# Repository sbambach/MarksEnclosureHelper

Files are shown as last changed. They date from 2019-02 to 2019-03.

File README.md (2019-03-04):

# Mark's Enclosure Helper 

This is an OpenSCAD script for generating a two peice hinged box, with
rounded corners, lid, interlocking rims, snap fit, magnet, or screw
closures, and easy places for adding cutouts or additions to any
face. All features are optional and specified by defining a few simple
variables. Included utility functions make perforations, text and
image decorations possible in a single line of code.

Additional parts inculding dovetails and belt clips are also included.

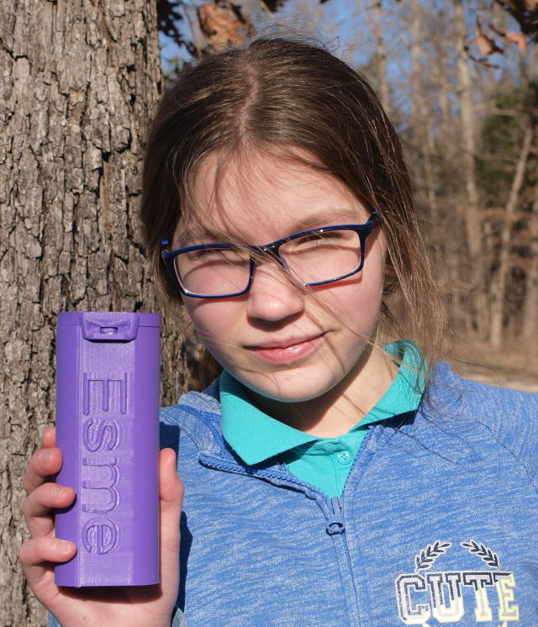
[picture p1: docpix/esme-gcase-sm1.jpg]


-----------------

We've tried to make this useable for those less comfortable with or even
new to OpenSCAD. See the "Let's Build a Bee Box" tutorial: 

[LETSBUILD-beebox.md](LETSBUILD-beebox.md).

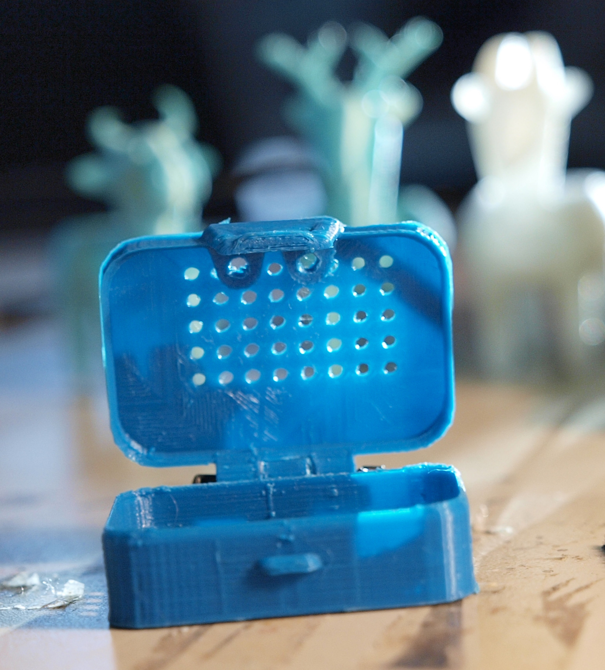
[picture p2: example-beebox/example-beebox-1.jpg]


-----------------

Experienced OpenSCAD users may wish to skip straight to the docs:

[REFERENCE.md](REFERENCE.md) 

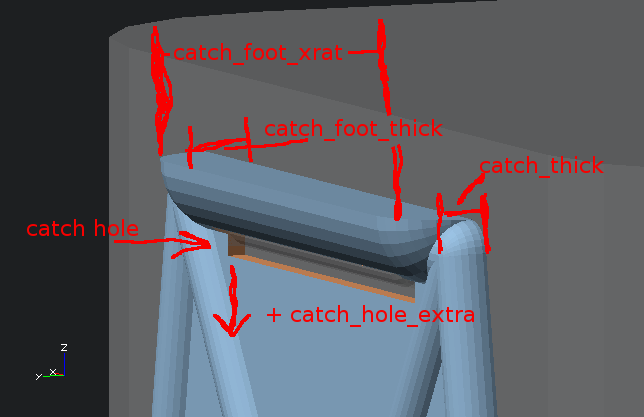
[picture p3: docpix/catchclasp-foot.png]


or to hacking at the included examples:

-----------------

[Eyeglass Belt Case](example-eyeglass-beltcase/)

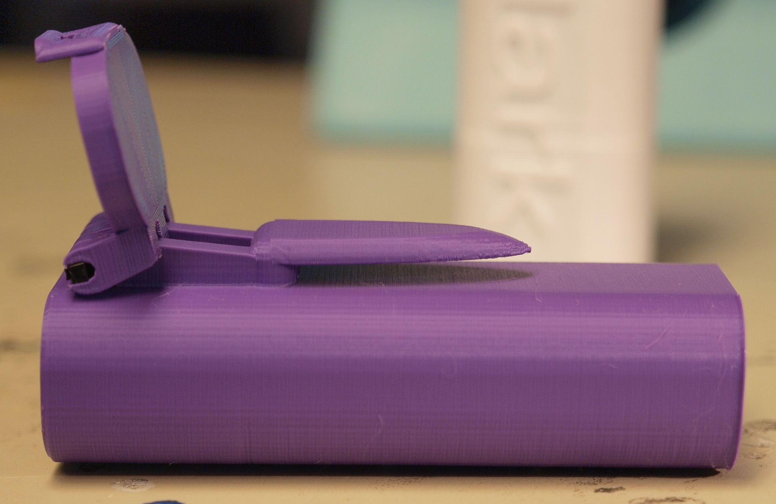
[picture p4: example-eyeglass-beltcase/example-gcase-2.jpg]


-----------------

[Interlocking Parts Boxes](example-partbox/)

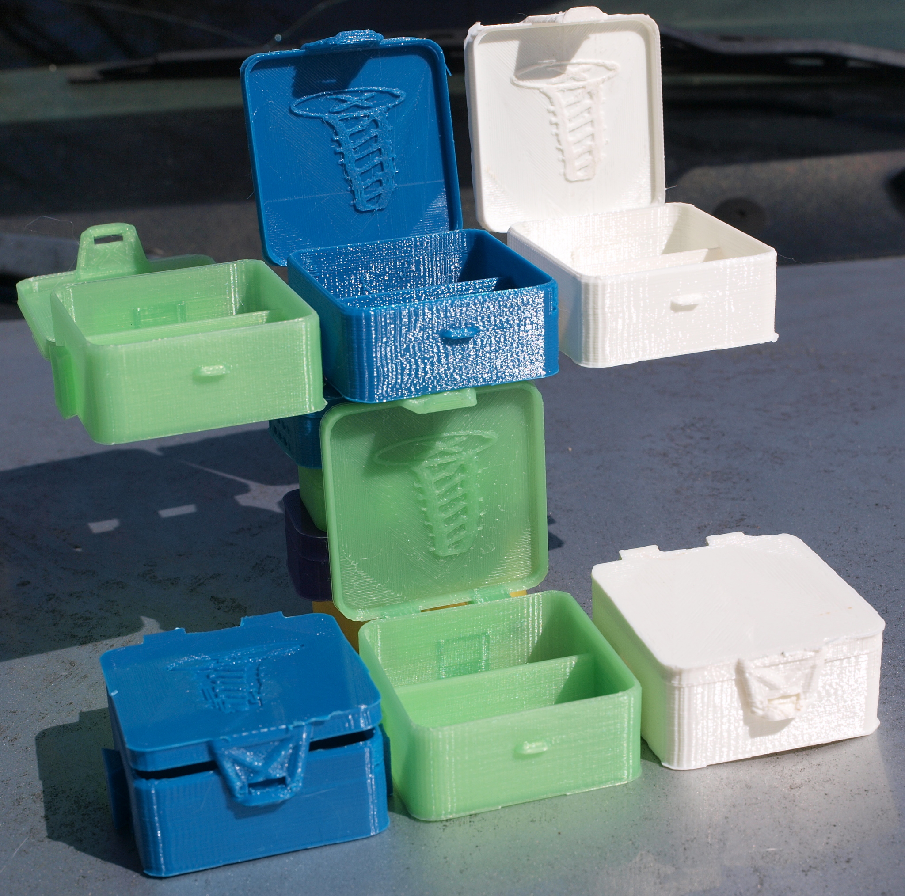
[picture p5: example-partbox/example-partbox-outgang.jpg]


-----------------

[Mini Mint Tin with Magnet or Catch Clasp](example-minitin/)

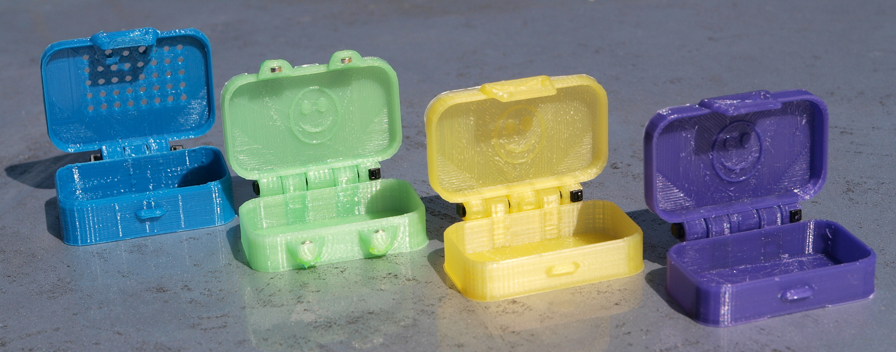
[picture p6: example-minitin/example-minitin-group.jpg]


-----------------

[Neddle Keeper with Sizing Guage](example-needlekeeper/)

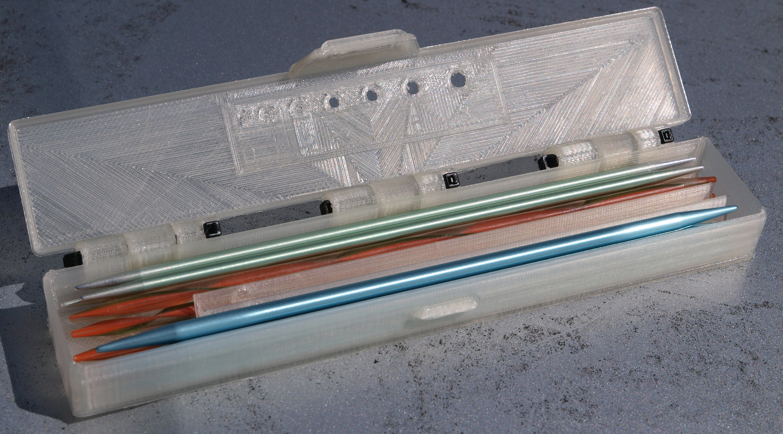
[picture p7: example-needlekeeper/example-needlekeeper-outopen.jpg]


-----------------

[4 Spool Thread Keeper](example-threadkeeper/)

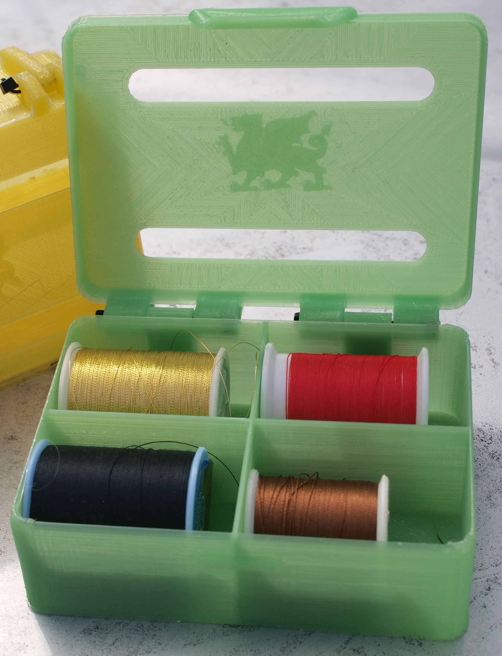
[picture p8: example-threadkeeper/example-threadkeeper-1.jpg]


-----------------

[Card Deck Case](example-cardcase/)

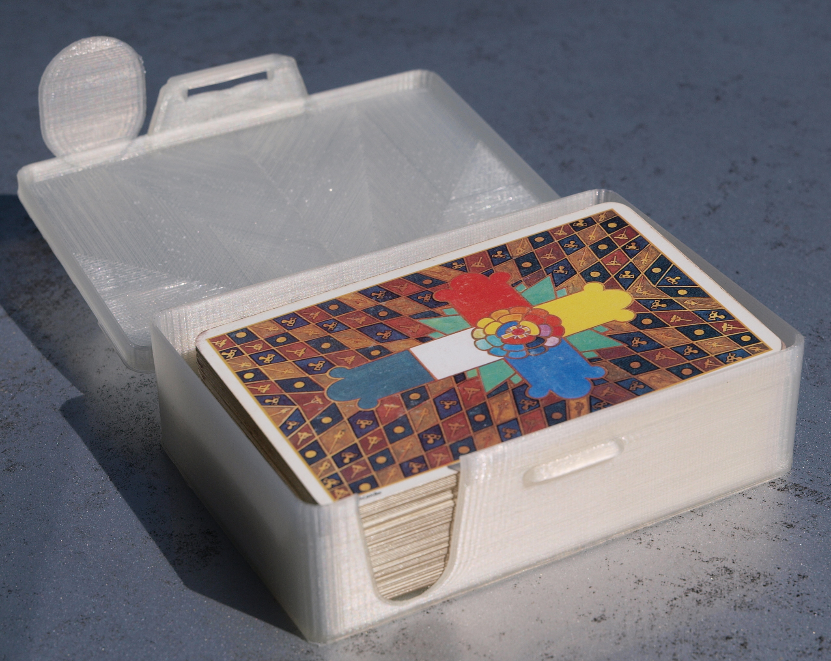
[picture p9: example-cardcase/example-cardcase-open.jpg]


------------------------------

We hope you find this code useful, and ask that you **[hit this donate
link](https://www.paypal.com/cgi-bin/webscr?cmd=_s-xclick&hosted_button_id=J3AY8SM43A2DA&source=url)**
please.

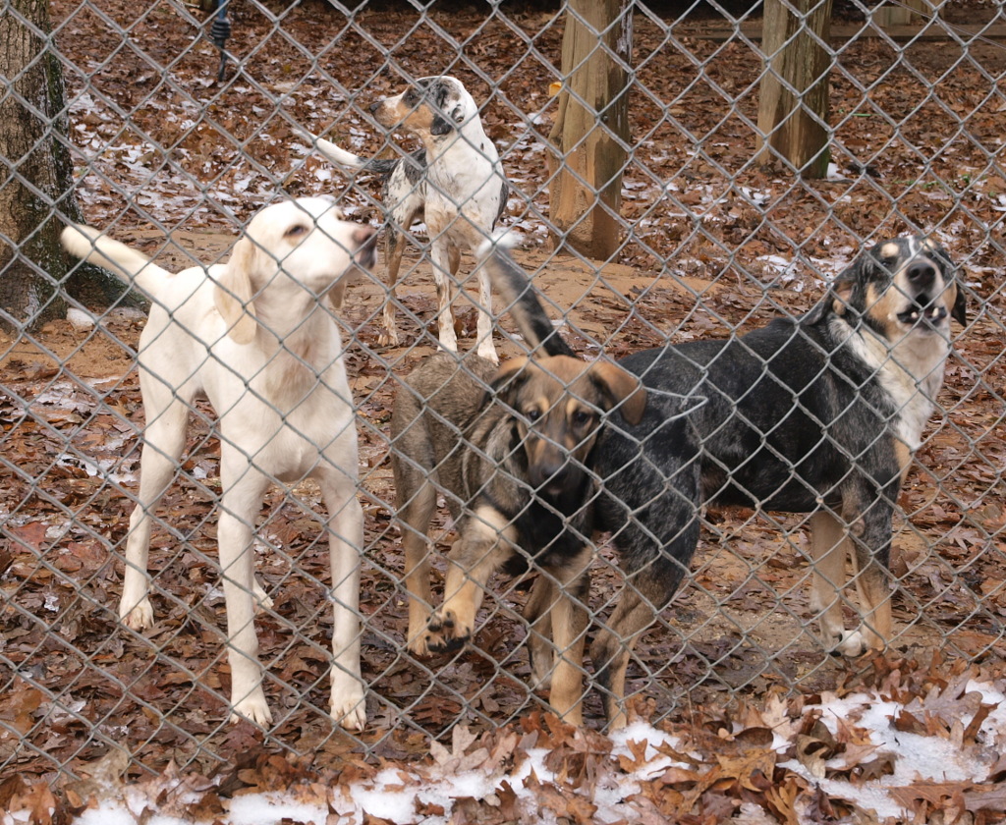
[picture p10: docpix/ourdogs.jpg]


We've got a large collection of mouths to feed and your generous
donations may help me convince my lovely, loving, and patient wife
that losing me to a coding project for the last month was
worthwhile. 

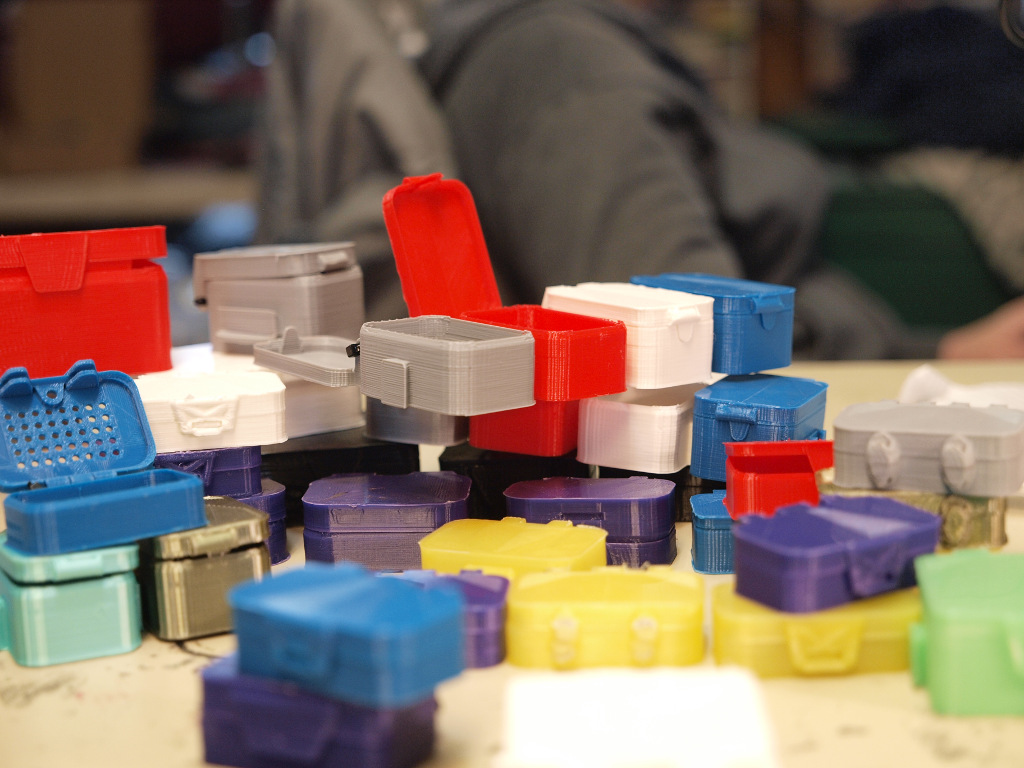
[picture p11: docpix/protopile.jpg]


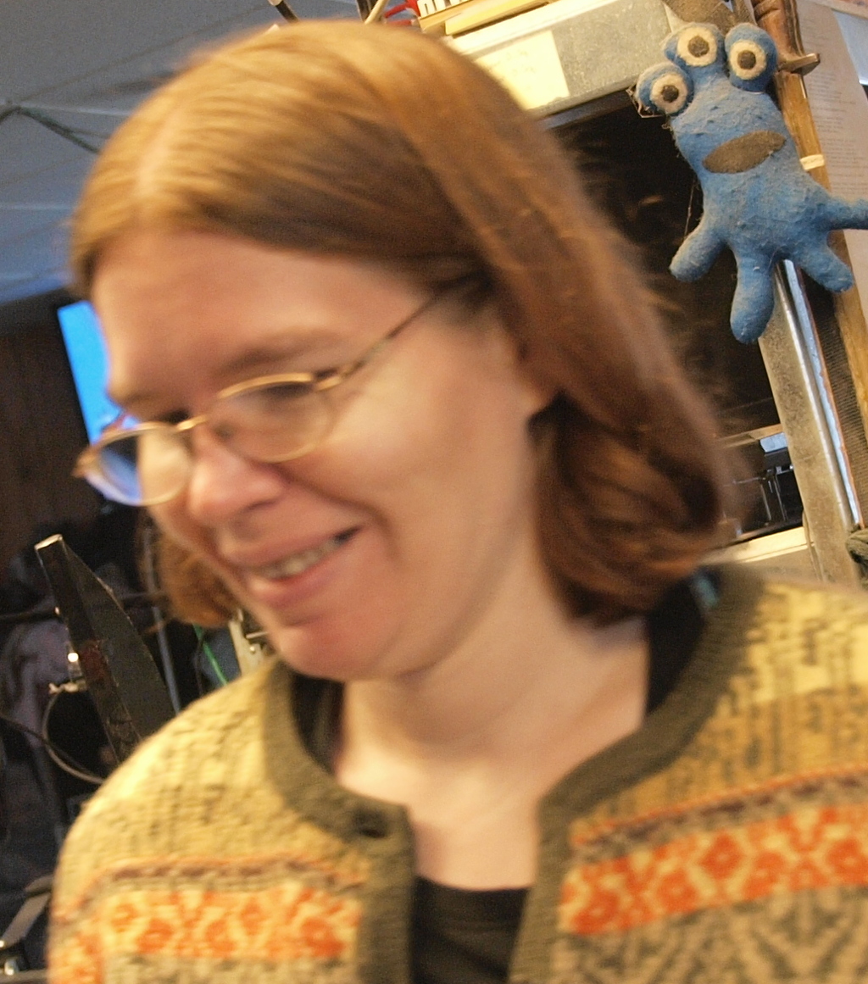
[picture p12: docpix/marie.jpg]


My inspriration :)

-------------------------------
   Copyright (c) 2019 Mark and Marie Lamb. Distributed under GPLv3, see LICENSE file for terms.

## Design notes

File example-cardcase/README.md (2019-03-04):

# Mark's Enclosure Helper - Card Case

This is a case to hold a (slightly oversize) deck of cards, with a
slot in the side to make accessing them easier. The corresponding
cover tab on the front keeps dust out when the box is closed.


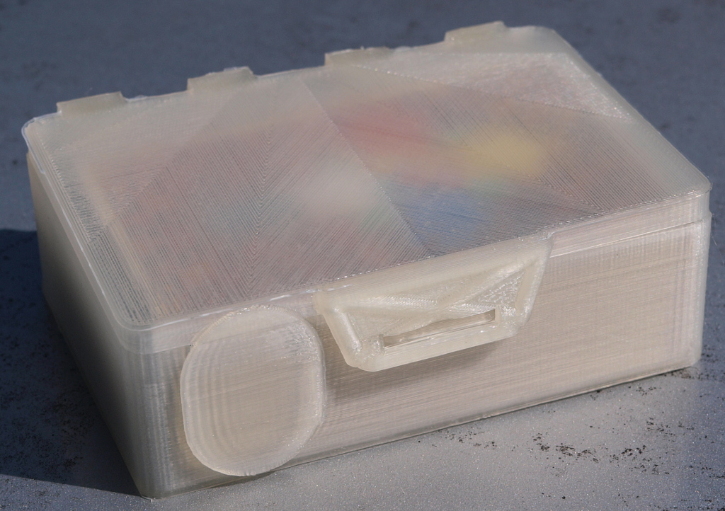
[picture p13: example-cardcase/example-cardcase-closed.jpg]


-------------------------------
   Copyright (c) 2019 Mark and Marie Lamb. Distributed under GPLv3, see LICENSE file for terms.

We hope you find this code useful, and ask that you **[hit this donate
link](https://www.paypal.com/cgi-bin/webscr?cmd=_s-xclick&hosted_button_id=J3AY8SM43A2DA&source=url)**
please.

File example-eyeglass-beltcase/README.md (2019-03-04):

# Mark's Enclosure Helper - Eyeglass Belt Case

Our daughter, Esme, got her first pair of eye glasses recently. Being
an American pre-teen her normal wardrobe has no place for her to keep
them safely as she goes about her daily activities. She needs a case
which that can attach to her clothing or back pack, that's tough
enough to survive the hectic and physical life she leads.

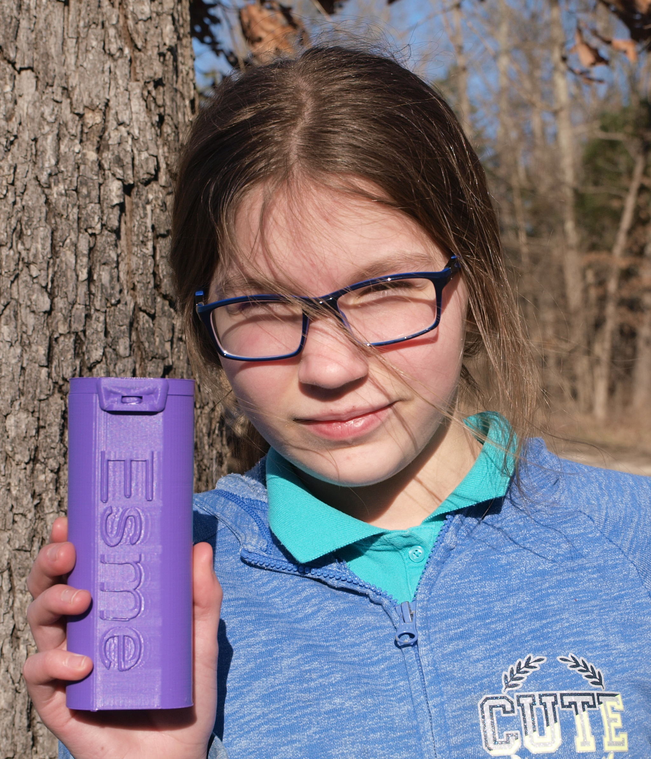
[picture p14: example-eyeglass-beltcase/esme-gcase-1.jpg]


This is after school the first day she's used this outside. It
survived!

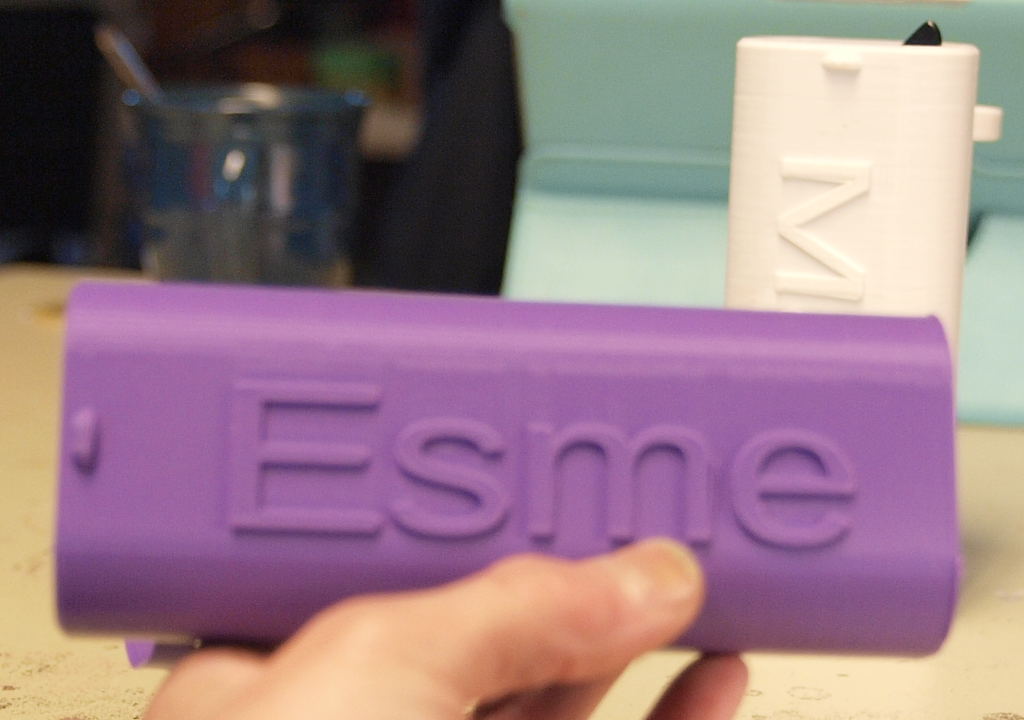
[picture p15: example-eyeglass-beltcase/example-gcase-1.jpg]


We've designed this box to be slightly difficult to open; the hinges
are offset slightly which adds extra "spring" to the top when its
closed. The hope is the box will open only by intent and effort and
accidental bumps and scrapes will not knock the lid loose.

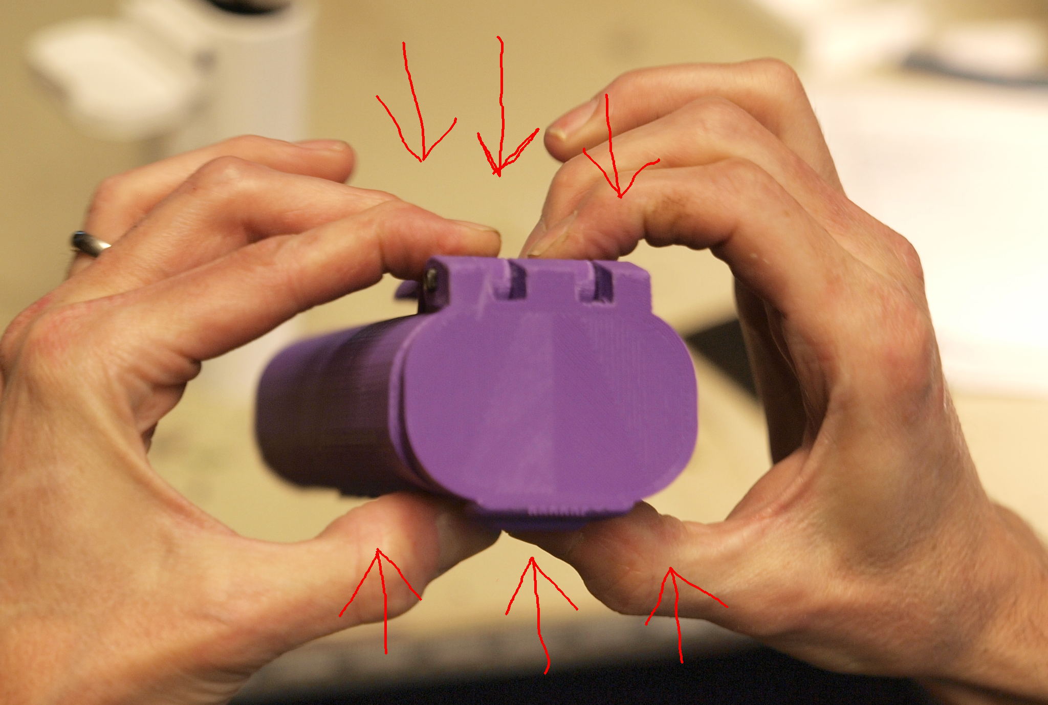
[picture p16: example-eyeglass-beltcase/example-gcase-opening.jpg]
opening box pic


Squeezing the front and back faces of the box together as shown should
result in the top popping up, possibly a small amount of force of the
clasp will be needed. Ours just pop open. 

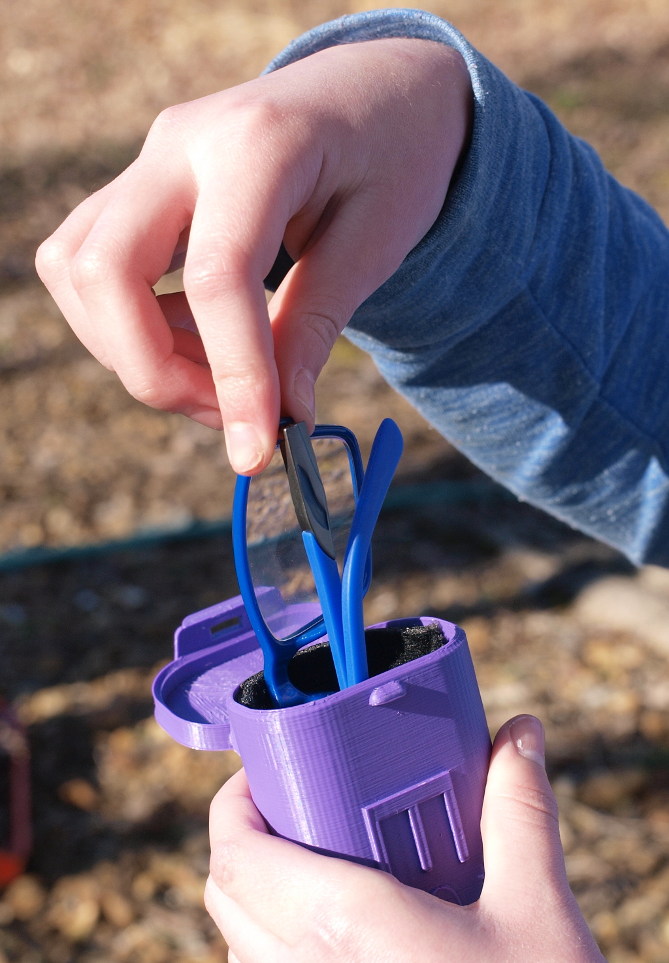
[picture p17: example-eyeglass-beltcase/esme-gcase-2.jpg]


You will need to line the box interior with something to keep the
lenses of eye glasses from getting scratched up by the plastic. We
sized the box to fit a pair of glasses in the cheap foam / leatherette
'reading glasses' cases we found to be ubiquitously available. Folded
a little bit and with the top trimmed it provides padding and
protection, and enough spare space for a pencil.

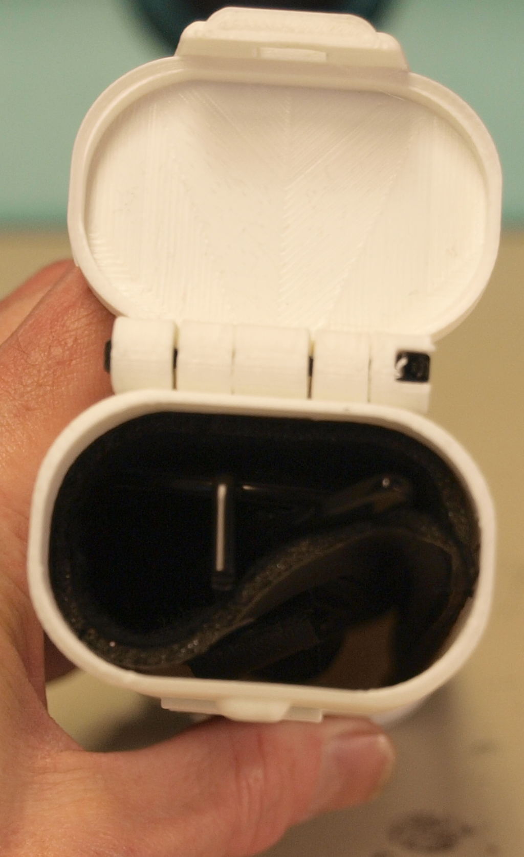
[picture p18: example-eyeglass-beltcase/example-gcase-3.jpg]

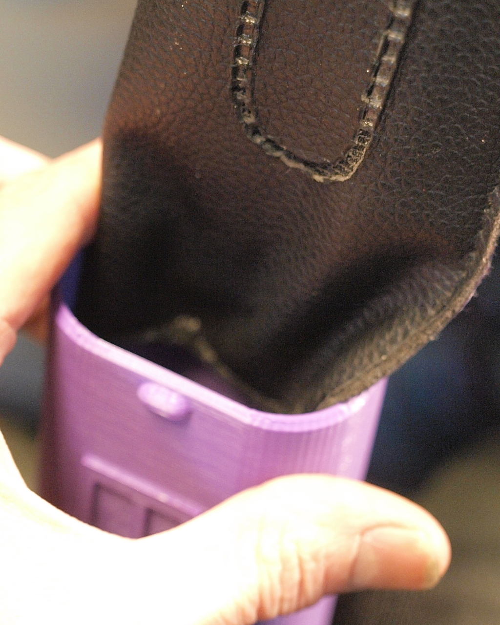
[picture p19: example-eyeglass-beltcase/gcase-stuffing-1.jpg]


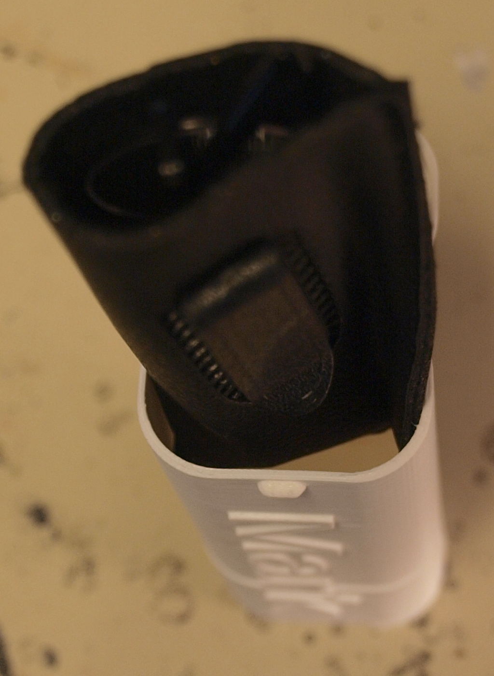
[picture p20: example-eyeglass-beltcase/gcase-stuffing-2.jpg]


>(This box suffered a layer shift during printing, but is still strong
>enough and pretty enough for what we needed).

We've provided STL files of a belt clip version (open on one side) and
a belt loop (closed on both sides of the loop). An adult size belt
will be thicker than the 5mm opening this model has. That size is
good for the camera bag strap we need it for.



====================================
## Printing

We've printed these in PLA with a 0.5mm nozzle, with support material
and brims. 

We suggest very high infill and/or soilid infill especially for the
body of the hinge and belt clip areas. 

We are using Slic3rPE, and the `solid infill threshold area` setting
in `Print Settings > Infill` is the variable that might cause the
infill to switch to solid in that part of the object if you have
trouble tracking that down. Other slicers certainly have a similar
value but we can't guide you about them.

See the [Box Assembly](../REFERENCE.md#box-assembly) instructions for
details of how to use two zip ties as hinge pins. an M3x40mm screw and
nut would also work (and have less play in the action) but those tend
to be expensive and hard to source.

====================================
## Design

The `hinge_standoff` value makes the top more firm when closed, by
changing the geometry of rotation of the lid when it opens. "The tooth
drags the catch harder" is the best explaination we can offer at the
moment. This also gives the top the "pop" spring when it opens.

The `catch_thick` at 3mm is **Very** thick for use, we hope its thick
enough to survive hard usage. Smaller fingers and gentler
circumstances would almost certainly find the catch easier to use with
a `catch_thick` of down to 1.5mm or so, and you might even want to
turn the `wall_thick` back down a hair.

The `hinge_basepoint` is set fairly arbitraily at 100mm, move it
freely for a different balance point, the box top hinges will need
room to fit when its open but otherwise the clip could run right up to
the top.

-------------------------------
   Copyright (c) 2019 Mark and Marie Lamb. Distributed under GPLv3, see LICENSE file for terms.

We hope you find this code useful, and ask that you **[hit this donate
link](https://www.paypal.com/cgi-bin/webscr?cmd=_s-xclick&hosted_button_id=J3AY8SM43A2DA&source=url)**
please.

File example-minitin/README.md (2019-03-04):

# Mark's Enclosure Helper - Mini Mint Tin
## with Magnetic or Catch Clasp

The famous mints used to (still may for all we know) have in "mini"
size, about 60mm x 35mm x 15mm, that was handy for all sorts of
things. We chose that size to devolp this generalized box code
against, as it's small enough to print in an hour and all the
prototypes can be given out to schoolchildren who will find them
charming regardless of their flaws.

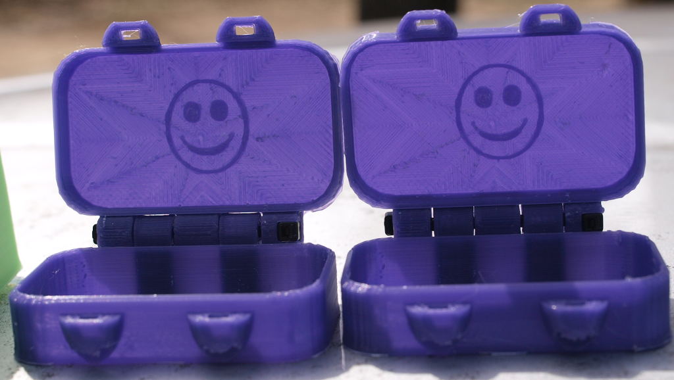
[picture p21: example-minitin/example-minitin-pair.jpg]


This code comes set up for a pair of magent holders for 6mm x 2mm round
rare earth magnets. We found those cheap in bulk online use them for
many things; if you find a different size you can adjust `magnet_d`
and `magnet_h` to fit what you have. You may also wish to adjust those
numbers to make the magnets harder or easier to insert.

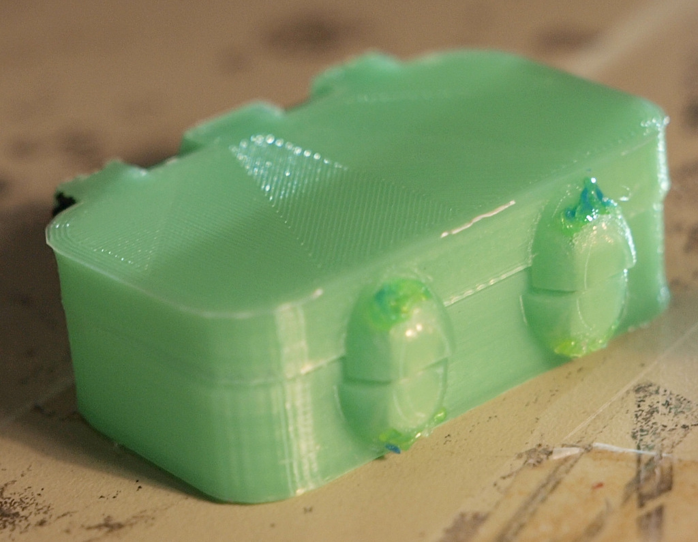
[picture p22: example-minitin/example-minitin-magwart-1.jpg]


The `magwart_box` calculation determines the outer dimensions of the
wart that carries the magnet, see the [magwarts
reference](../REFERENCE.md#magwarts) for full documentation. For
immediate use you can change the sqish by playing with the `1.0` and
`1.6` values, which are distoriting the X and Y dimensions of the
magwart.

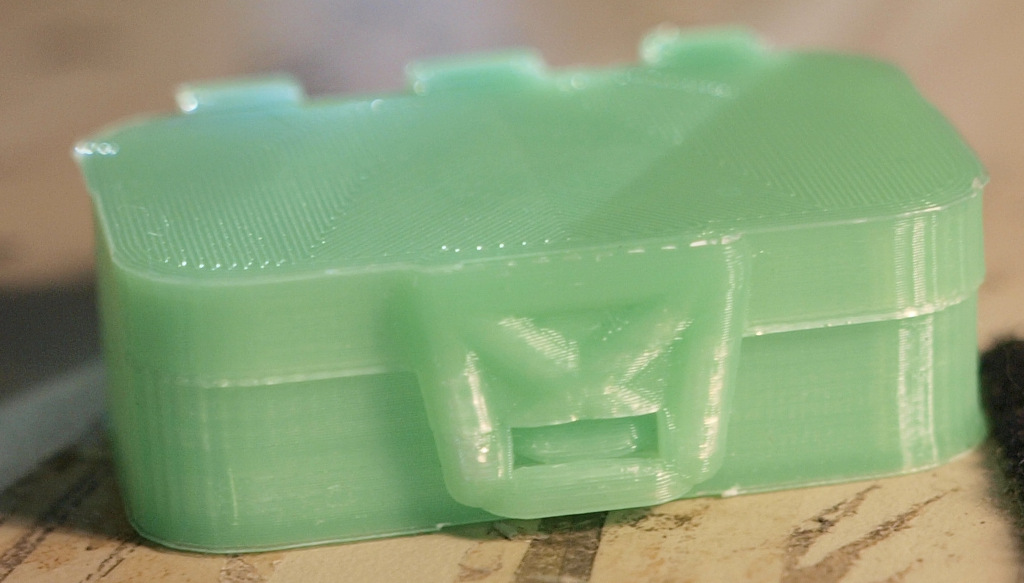
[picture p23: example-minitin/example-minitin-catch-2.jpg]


To use a catch clasp, comment out the `magwart_points` variable, and
uncomment the `catch_points` definition. In other words, make the file
look like this:
```
catch_points=[0.5];

//magwart_points = [0.3,0.7];

```

For further control of the clasp see the [catch clasp
reference](../REFERENCE.md#catch-clasps).

## Printing

We have printed these with 0.4mm, 0.5mm, and 0.6mm nozzles, in several
varietes of PLA, with and without supports and with and without print
cooling fans. Supports and fans can make details sharper but are not
striclty necessary.

At this wall thickness slicer settings having to do with perimiters
control more than infill. Our slicers have consistiently made the
hinge legs solid; they should function pretty well with lighter infill
as long as the perimiter is still firm enough to keep the shape.

-------------------------------
   Copyright (c) 2019 Mark and Marie Lamb. Distributed under GPLv3, see LICENSE file for terms.

We hope you find this code useful, and ask that you **[hit this donate
link](https://www.paypal.com/cgi-bin/webscr?cmd=_s-xclick&hosted_button_id=J3AY8SM43A2DA&source=url)**
please.

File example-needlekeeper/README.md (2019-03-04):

# Mark's Enclosure Helper - Needle Keeper with Sizing Guage

Marie's second foray into more complicated OpenSCAD code is a box for
sorting and storing douple pointed knitting neeldes.

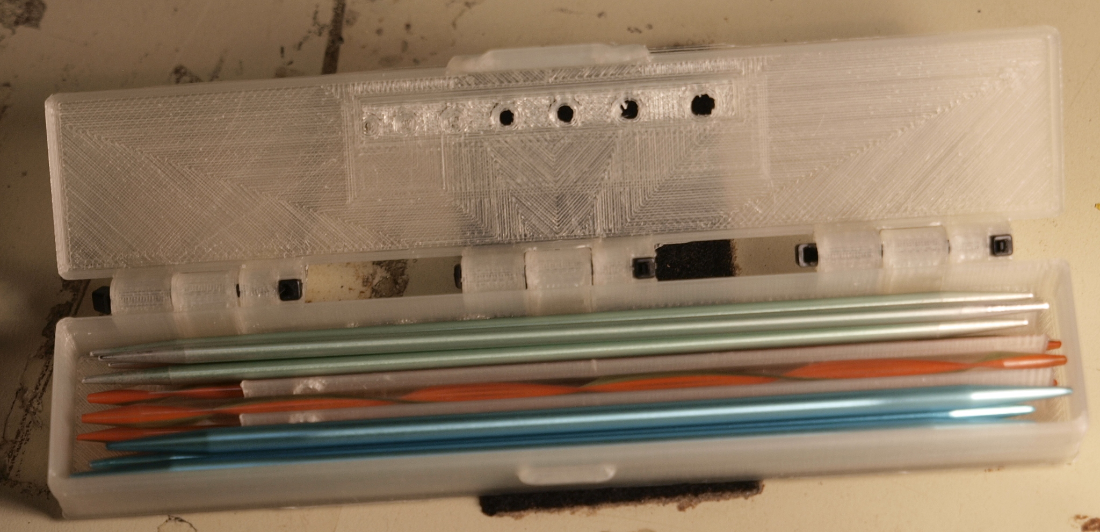
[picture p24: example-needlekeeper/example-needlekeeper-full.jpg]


The insert is a bit of custom (read hacked) code to make freestanding
ribs at a declining angle. This and the needle guage can both be done
more elegantly, but this serves the purpose and makes a functional
shape.

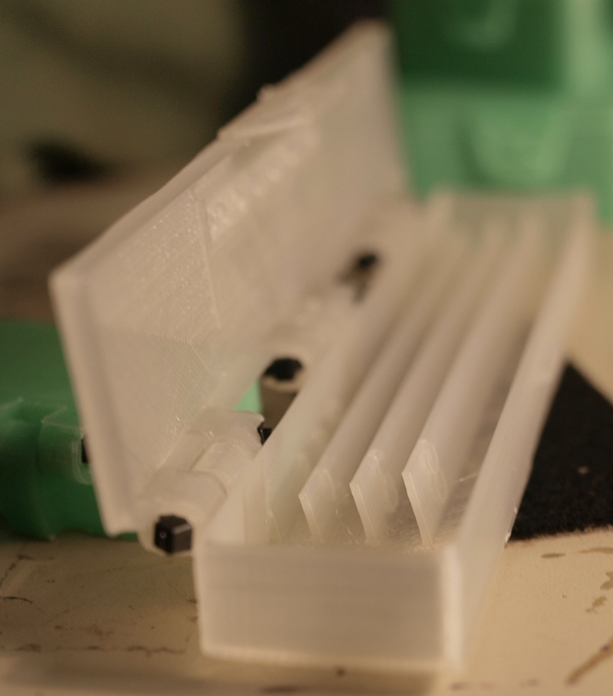
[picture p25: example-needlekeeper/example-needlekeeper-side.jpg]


The sizing guage has text labels on the holes; which aren't visible
with the transparent PLA we printed the first example in. The holes
themselves required some post-print cleanout.

-------------------------------
   Copyright (c) 2019 Mark and Marie Lamb. Distributed under GPLv3, see LICENSE file for terms.

We hope you find this code useful, and ask that you **[hit this donate
link](https://www.paypal.com/cgi-bin/webscr?cmd=_s-xclick&hosted_button_id=J3AY8SM43A2DA&source=url)**
please.

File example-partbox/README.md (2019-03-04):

# Mark's Enclosure Helper - Interlocking Parts Box

Having purchased 10 M6 and 10 M10 screws with some effort and and
untenable expense, we're reluctant to chuck them into the
"Misc. Screws" bin and have to dig for them when we need one sometime
later. Therefor these small boxes to hold small quantities of things,
in a semi-organized and orderly way.

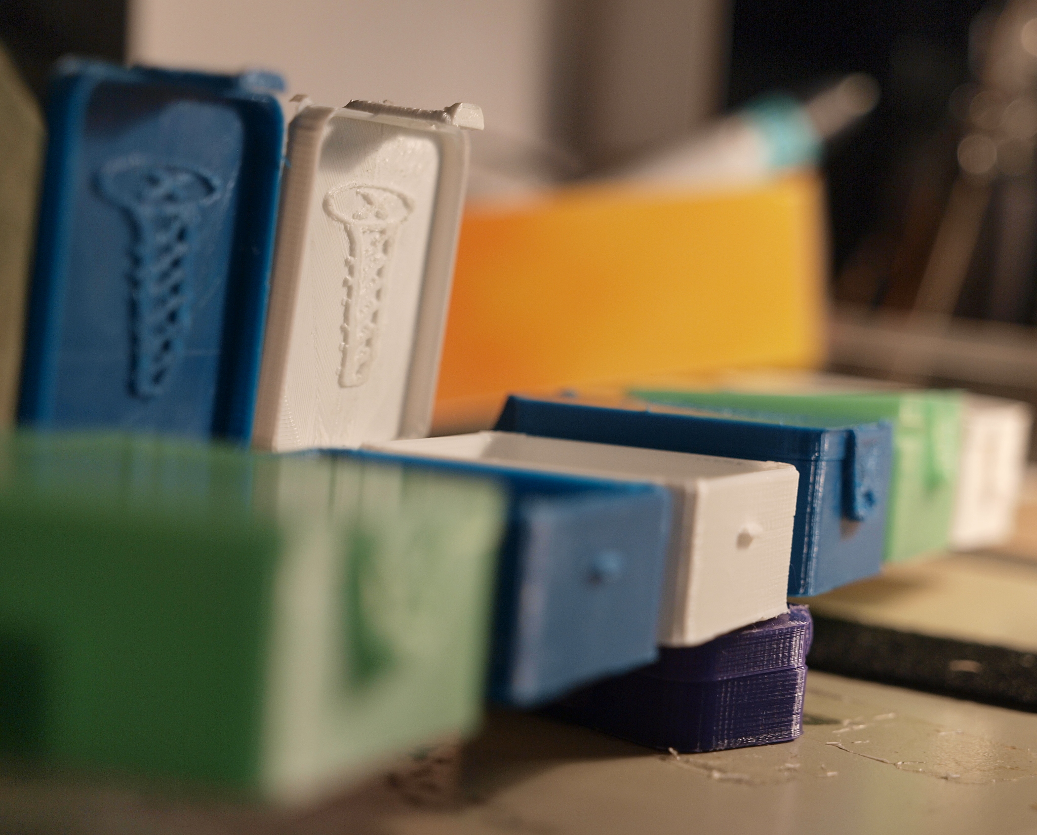
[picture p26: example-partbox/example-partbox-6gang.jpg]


These boxes use dovetails to interlock, those are defined in the code
with `dtspec` and associated variables. See the [dovetails
reference](#../REFERENCE.md#dovetails) for details.

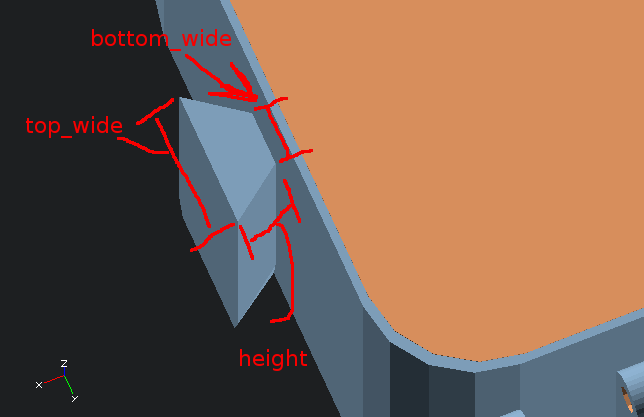
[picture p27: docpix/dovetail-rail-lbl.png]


These are 4mm x 14mm in the dovetail portion, with a bit of a taper at
the bottom to make sliding them together easier. If you print with a
brim (which we always do) you may wish to pay attention to how you
trim around the dovetail; leaving the bottom of the block side filled
in can be a handy "floor".

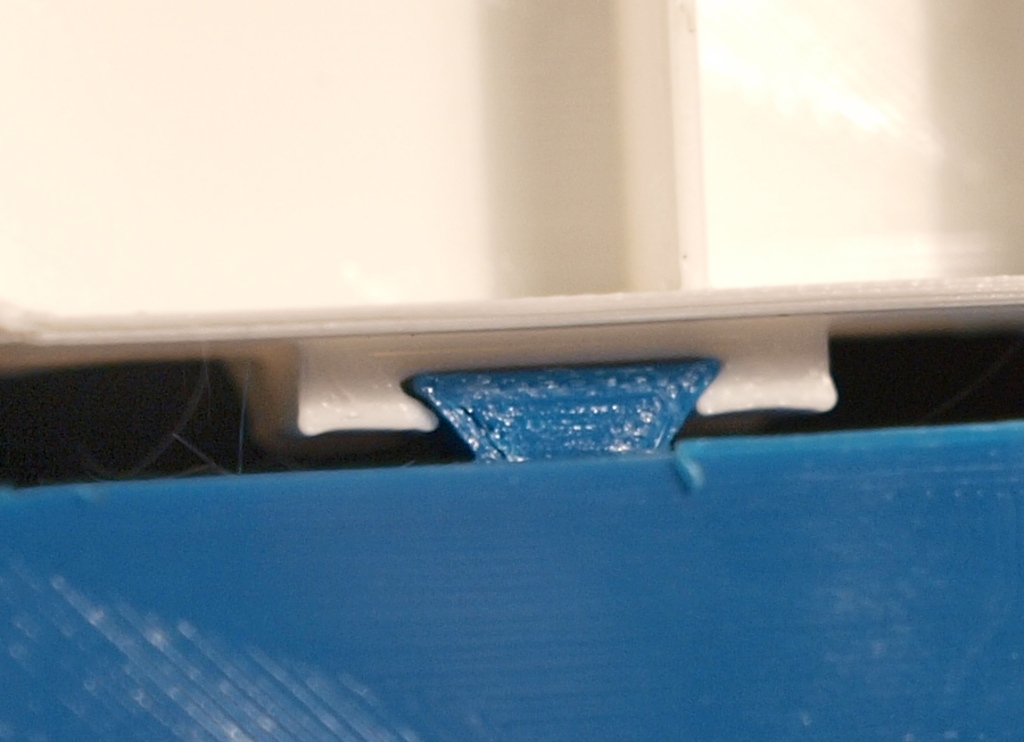
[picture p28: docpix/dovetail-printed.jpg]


We have printed these with 0.4mm, 0.5mm, and 0.6mm nozzles in several
different types of PLA and had them all interlock and work together
well. Supports and print cooling are both beneficial but not truly
necessary.

If you need to increase the space between the dovetail parts to make
them easier to slide together, increase the `dt_CLEAR` variable in the
`example-partbox.scad` file. Try steps of 0.2mm to your nozzle width
to begin with.

-------------------------------
   Copyright (c) 2019 Mark and Marie Lamb. Distributed under GPLv3, see LICENSE file for terms.

We hope you find this code useful, and ask that you **[hit this donate
link](https://www.paypal.com/cgi-bin/webscr?cmd=_s-xclick&hosted_button_id=J3AY8SM43A2DA&source=url)**
please.

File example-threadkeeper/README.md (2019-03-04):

# Mark's Enclosure Helper - 4 Spool Thread Keeper

When we had this code almost useable, Marie bravely threw herself into
depths of OpenSCAD she had not yet explored and created this and the
[needlekeeper](../example-needlekeeper/) to see if someone else could
successfully create a box. She succeded.



This holds 4 spools of thread, with cutouts so you can see the colors.

The dragon is from the Welsh flag; she's been learning Welsh
recreationally for some time now. He's pretty enough to be seen more.

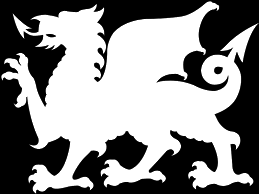
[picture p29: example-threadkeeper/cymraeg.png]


## Printing

We've printed this in PLA with a 0.6mm and a 0.4mm nozzle (earlier
prototype with different hinges). These boxes generally are easy to
print and should be very forgiving or errors. Supoports and print
cooling are not necessary but will enhance details.

-------------------------------
   Copyright (c) 2019 Mark and Marie Lamb. Distributed under GPLv3, see LICENSE file for terms.

We hope you find this code useful, and ask that you **[hit this donate
link](https://www.paypal.com/cgi-bin/webscr?cmd=_s-xclick&hosted_button_id=J3AY8SM43A2DA&source=url)**
please.

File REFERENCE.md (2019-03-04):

# Mark's Enclosure Helper - Reference

  https://github.com/h2odragon/MarksEnclosureHelper
 
Copyright (c) 2019 Mark and Marie Lamb. Distributed under GPLv3, see
LICENSE file for terms.

- [Features](#features)
- [Usage](#usage)
- [Box Assembly](#box-assembly)
  - [Magnet Insertion](#magnet-insertion)
- [Main Modules](#main-modules)
  - [Layout Variables](#layout-variables)
- [Box](#box)
- [Hinges](#hinges)
- [Catch Clasps](#catch-clasps)
- [Magwarts](#magwarts)
- [Screw Towers](#screw-towers)
- [Callbacks](#callbacks)
- [Parts](#shapes)
  - [Dovetails](#dovetails)
  - [Wartclip](#wartclip)
- [Utilities](#utilities)
  - [diecut()](#diecut)
  - [center_scale()](#center_scale)
  - [slots()](#slots-yslots-and-grid)
  - [yslots()](#slots-yslots-and-grid)
  - [grid()](#slots-yslots-and-grid)
  - [cyl_grid()](#cyl_grid)
  - [dividers()](#dividers)
  - [cylinder_half()](#cylinder_half-capsule-capsule_qtr)
  - [capsule()](#cylinder_half-capsule-capsule_qtr)
  - [capsule_qtr()](#cylinder_half-capsule-capsule_qtr)
  
-----------------------------------------------------
## General Overview

>
>"Meh. It's a box."
>

We wanted to make it easier to make custom enclosures using
OpenSCAD. When you want a box, you want it for a purpose and you want
the features like the custom insert to hold **your** thing, or the
name of the recipient for a gift box embossed on it.

We certainly did. It turns out that even with the plethora of designs
shared already, few of them were adaptable to the list of enclosures
we already wanted to make, and none easily. We'll grant you we
could've spent more time looking.

Our hope is that this package fills that void. If you need a box with
a hinged lid, snap fit or magnetic catches, optional rim and rounding,
then this can be the box for you, and you can spend your time and
ingenuity on the "everything else" that makes it yours, while our code
does the boring box things for you.

If you find this project useful, **[PLEASE DONATE](https://www.paypal.com/cgi-bin/webscr?cmd=_s-xclick&hosted_button_id=J3AY8SM43A2DA&source=url)**, thanks! 

-----------------------------------------------------
## Features

* Rounded rectangular box, with top and bottom. You specify size and
   where the top and bottom are split. Shape can be distorted to
   nearly circular.

* Extensive, illustrated reference documentation.

* Beginner freindly tutorials. (Well, [one so
  far](LETSBUILD-beebox.md) but we intend to add more.)

* Several simple and more advanced examples provided.

* Parametric design: You provide the important definitions of size,
  and placement of features such as hinges and closures, and the code
  makes everything fit together.

* Optional overlapping rim between top and bottom.

* Hinges of any number and size along the back of the box. Hinges can
  be shaped and sized as your purpose requires and the hinge pin
  hardware you supply dictates.

* Set the hinge rotation axis anywhere, the design adjusts.

* Multiple closure options: Snap together catch clasps, magnet
  holders, or reinforced tie points. Or make your own and apply them
  to the box with two lines of code.

* Internal dividers can be created with one line of code; your own
  custom insert structures can be applied as easily.

* Fully control the sizes and shapes of many features, but with
  reasonable default values that should "just work" in most cases,
  tested on a variety of equipment.
  
* Easily perforate / decorate / complicate whichever face of the top
  or bottom of the box you please. You're free to work on getting your
  decorations as you like them, while our code takes care of the fiddly
  positioning and orientation for you.

* Interlocking dovetail shapes provided for grouping boxes together. 

* Easy to print: We've had success printing with and without supports,
  using several printers and nozzle sizes. We've even had some
  functional if ugly examples that suffered layer shifts, alignment
  errors, and other common printing issues.

-----------------------------------------------------
## Usage

`include <hingebox_code.scad>` in your own OpenSCAD script, define
whichever variables you need, and call `hingedbox( box_def )`.

If that didn't make any sense please see the
[beebox](LETSBUILD-beebox.md) tutorial.

A simple box script might look like this:
```
include <hingebox_code.scad>

hingedbox( box_def );

box_def = [60, 35, 20]; 
wall_thick = 1.2;  
top_rat = 0.35;  
lip_rat= 0.05;  

hinge_points = [0.5];
hinge_len = 22; 

catch_points=[0.5];
```
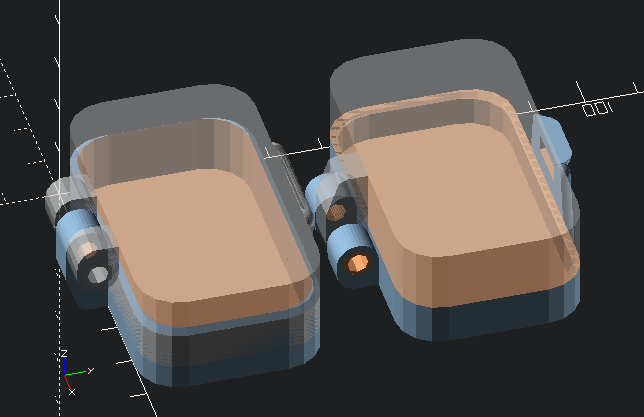
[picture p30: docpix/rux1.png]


### Licensing and Remixing

We're distrubiting this code under the GPLv3. That's a well known
license but we're not certain of the implications for 3d printing
work. We'll make our intent clear as possible:

YOU MAY use `hingebox_code.scad` as part of your OpenSCAD script to
generate a model (STL file, etc) that you then distribute,
commercially or otherwise, without any obligation from us to publish
your code. We would appreciate mention and a link to our GitHub page
in that case, but you are not obliged.

If you distribute your `.scad` file as well; you need not include
`hingebox_code.scad` with your package, and should instead point users
to the GitHub page with a link so they may access the latest revisions
if any. We do not assert any rights over how you may license such a
release. We do require attribution, a simple "uses
github.com/h2odragon/MarksEnclosureHelper" will satisfy us. 

If you change OUR CODE, the `hingebox_code.scad` file, the example
boxes, and distribute that, then you MUST also publish your changes to
our code as part of that distribution. We thank you for contributing
to Free Software. We would prefer potential new users be introduced to
the whole distribution, including documentation, so please include the
whole archive you got when copying on.

If you need different license terms, please get in touch.

### Disclaimer

Any and all personal and organizational use of our code that do not
involve distribution of actual bits we generated, are not our
responsibility and have nothing to do with us. We do not warrant this
code to be free from defects, suitable to any purpose, able to make
delicious candies, or to be of any utility at all. In the event of
unexpected performance or interfeference with performance of any other
information or belief system we can offer no remedy.

-----------------------------------------------------
## Box Assembly

Assembling the box is straightforward, peel any brim and support
material, and place the box top on the bottom. Everything should fit
together smoothly.

If you're using a screw and nut for the hinge pin, put them in now,
and you're done. That's a durable and easy solution which we have used
on several boxes. It could get expensive quickly if you don't stock
large amounts of hardware, however. And it's often hard to find a long
enough screw, so you may have to resort to plastic substitutes.

We've been using 4 inch zip ties for hinge pins while printing
prototype boxes, and developed a technique we think
worth sharing. You'll need two ties to make a hinge pin. We're
illustrating using a box with [hinge ziptie notches](#hinge_ztnotch)
but it works as well with the ties protruding.

Insert the first tie through the hinge, so that the tie's block (the
fat bit at the end) could slide into the notch.
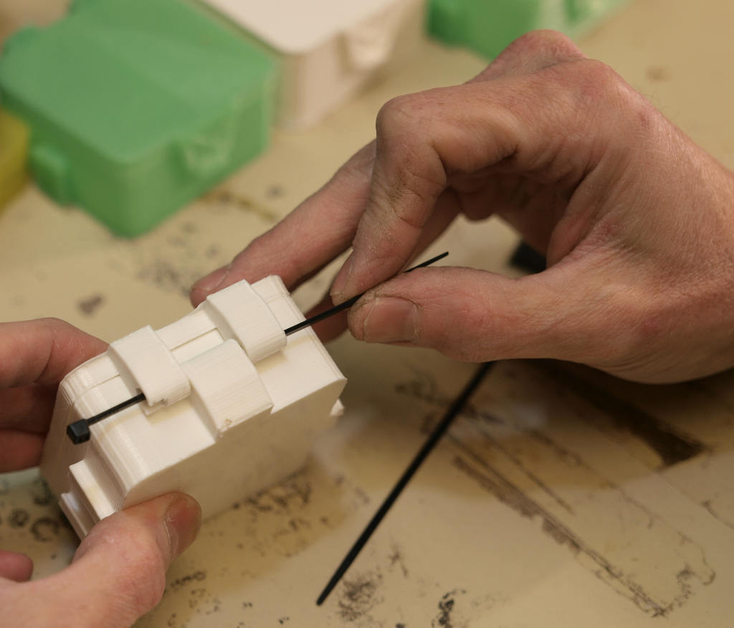
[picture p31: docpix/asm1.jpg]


The second tie slides onto the first, yin-yang style:
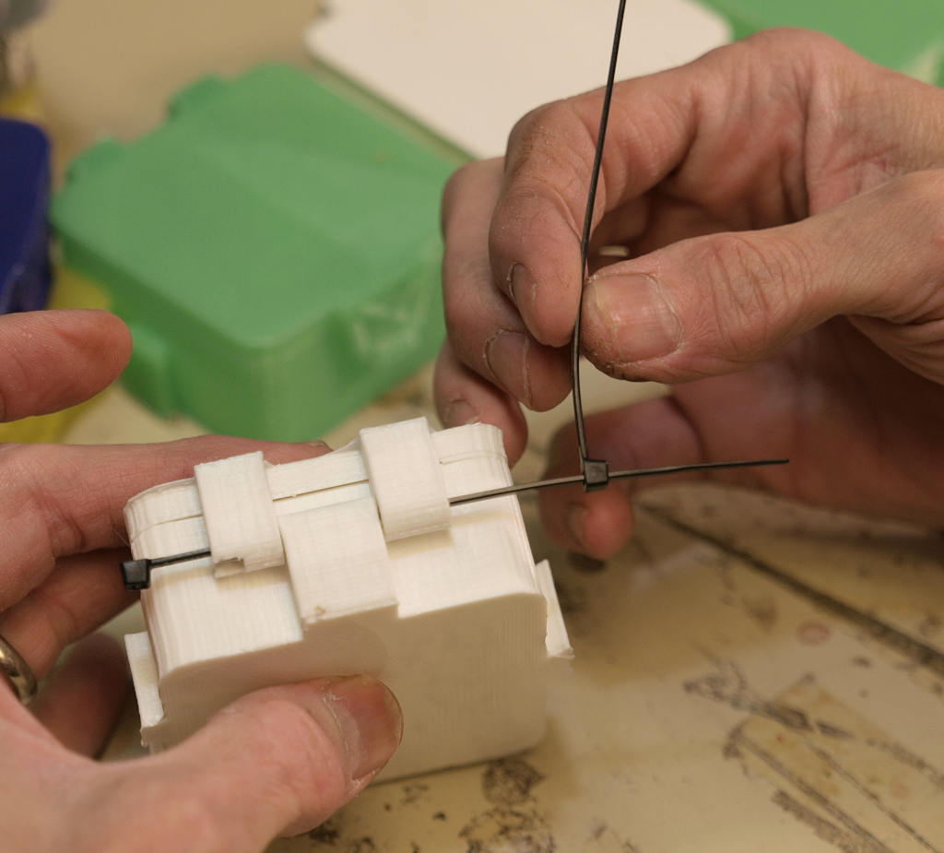
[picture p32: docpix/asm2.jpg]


The free end of the second tie goes through the hinge hole:
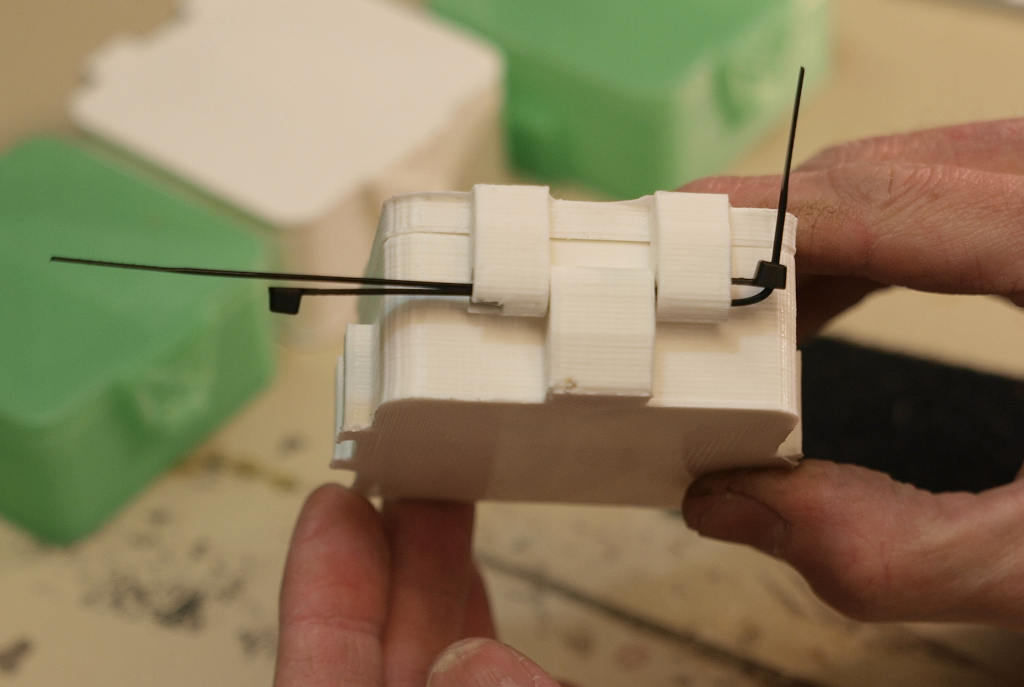
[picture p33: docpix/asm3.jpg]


And then through the block of the first tie.
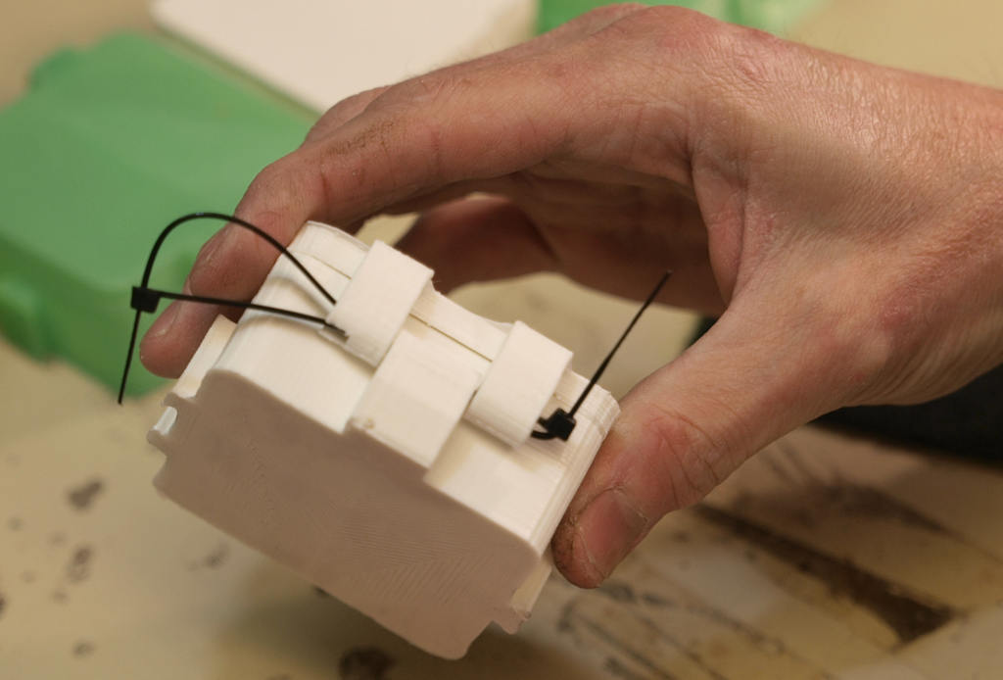
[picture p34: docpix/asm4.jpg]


You will probably want pliers to pull the ties tight.
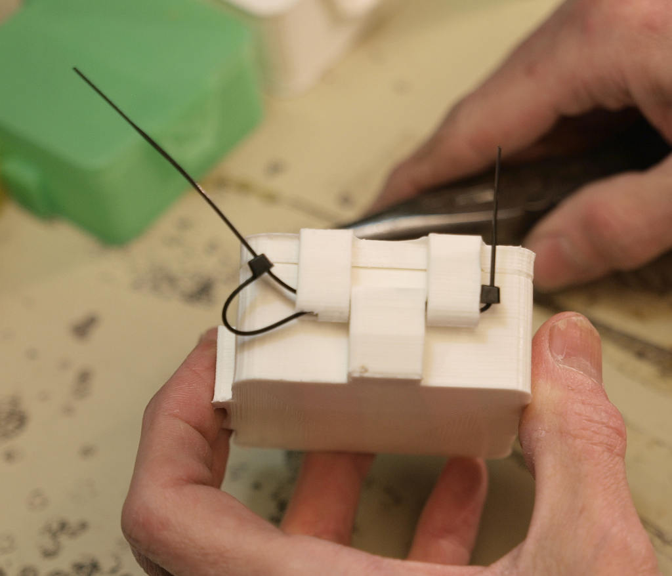
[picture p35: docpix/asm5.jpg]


Titghten one tie almost all the way down, then pull the other tie
fully titght.
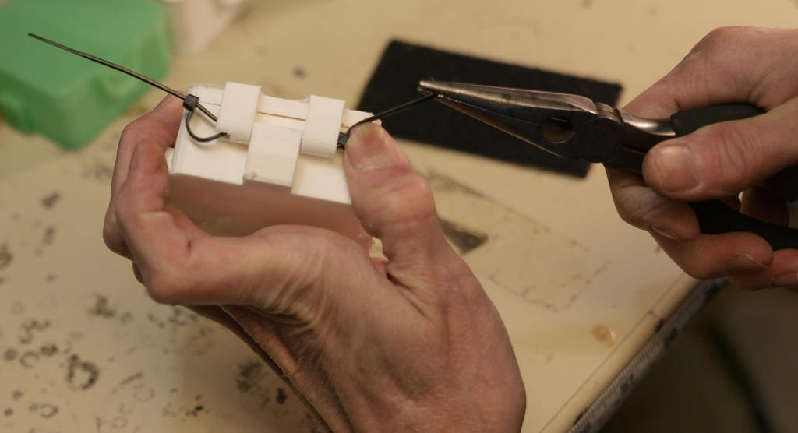
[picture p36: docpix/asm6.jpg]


Snug up the first tie


As you pull the ties in, make sure they line up with the notches


When using notches the ties can, with care, be completely
hidden. Keeping them out of the way is often good enough.


Cut the excess material off (very close to the block, the one side
will rub the box as the lid opens if there's much leftover).


Your hinge now has an effective **cheap** pin that should last as long
 as the rest of the box.



-----------------------------------------------------
### Magnet Insertion

Slide one magnet into either the top or bottom magwart. Use that to
determine the correct orientation for the second magnet, so that they
attract one another instead of pushing each other apart. Slide the
second magnet into the other magwart, being sure to keep the magnet
oriented properly. Getting one back out can be frustrating.

You should do something to ensure the magnets can't fall out of the
magwart body. We've used superglue, hot glue, and hot plastic blobbed
on with a "3d Pen" extruder; all worked well. The plastic looks best,
we think. Gluing in a bit of filament might work too.

-----------------------------------------------------
## Main Modules

### hingedbox
=======================
```
module hingedbox( d ) {}

- Creates the box top and bottom, laid out beside one another, with
  the other half of each optionally shown in place as a ghost. 
```

Uses `VIS` flag to show ghost assemblies and `PART_SPACE` to add
distance between parts.

### hingedbox_half
=======================
```
hingedbox_half( d, topflag=false) {}

- Build top or bottom half of box `d` based on boolean `topflag`
```

The actual meat of the code happens here. 

### Layout Variables
=======================
```
// show ghosts, top/bottom and magnets
VIS=true;  

// extra space between top and bottom for printing
PART_SPACE= 2; 
```
=======================

-----------------------------------------------------
## Box

These variables define the dimensions and shape of the box, where the
top and bottom split, and the size of the overlapping rim between the
two.

`CLEAR` is a global parameter applied wherever parts meet.

=======================
```
// width (x), depth (y), height (z)
box_def = [60, 30, 30]; 

// wall thickness (all around)
wall_thick = 2;  

// how much height (z) is top (rest is bottom)
top_rat = 0.15;  

// height (z) of lid lip overlap chamfer (0 to disable). 
//  (should be less than top_rat)
lip_rat= 0;  

// box corner radius
corner_radius = 8;  

// box corner $fn
corner_fn = 16;     

//nut inset dia and nut inset thick (depth)  
// used in hinge and screw tower, disable by setting hnut_t = 0
hnut_d = 6; hnut_t = 0; 

// space between hinge parts, top/bottom screw towers
CLEAR=0.6;  
```

Box Variables

### box_def

[X, Y, Z] specification defining the outside of the box body. The
inside is reduced by `wall_thick`. Hinges, claps and other features
will protrude outside the box body.

### wall_thick

Thickness of walls. Used in the box body and several other places.

### top_rat

Factor applied to `box_def.z` to determine the box lid height. If
`lip_rat` is nonzero, there will also be a hollowed out rim around the
lid which will overlap the bottom when assembled.

### lip_rat

Factor applied to `box_def.z`, determines height of overlapping lip on
the top and bottom box parts.

### corner_radius

Radius of the cylinders making up box corners. Will produce strange
results when greater than half of `box_def.y`

### corner_fn

$fn of box corner cylinders.

### CLEAR

General 'clearance' value used in many places. Primarily between top
and bottom hinge parts, but also used most anywhere else parts fit
together. We've had success with the default value of 0.6mm on
printers using 0.4mm, 0.5mm, and 0.6mm nozzles.

### hnut_d, hnut_t

Diameter and thickness of hexagonal nut incised from outer hinge faces
and scretower holes. Set `hnut_t = 0` to disable.

-----------------------------------------------------
## Hinges

The hinges join the top part to the bottom and rotate around a hinge
pin you supply. We've designed around and used M3 size screws and
paired 4 inch zipties as hinge pins. Zipties are cheap, durable,
and easy to assemble, so we reccomend them fondly.

=======================
```
// height of hinge axis; % of total height (aka dz or box_def[2] )
hinge_zrat = 0.70; 

// points along width (x)  to place hinges, leave empty for none
hinge_points = [ ];  
  
// length of single hinge; splits top/bottom by hinge_xrat
// anything under 10 is probably too delicate to use
hinge_len = 16; 

// how much hinge_len is bottom tower. (>1 taken as a concrete unit)
//   ( the hinge top splits the rest in half, on the outside of the lower hinge)
hinge_xrat = 0.33; 

// if you want to separate the hinge towers from the box body
hinge_standoff = 0; 

// where the hinge leg bends (z), % of hinge height
hinge_midpoint = 0.5; 

// where the hinge leg ends. <1 * lz, >1 taken absolute.
hinge_basepoint_bottom = 0;
hinge_basepoint_top = 0;

// diameter of hinge root cylinder
hinge_root_d = false; // hinge_id;

// the diameter of the outer hinge cylinder
hinge_od = 8; 

// hinge_id of 3.8 to 4.0 works for m3 screw and 4in ziptie
hinge_id = 4.0;  

// size of hole to put through hinge_midpoint; 0 to disble
hinge_mid_hole = 0;

// outer $fn for hinge, and inner $fn for hinge pin hole
// keep outer high; hinges rub the other half of the box without standoff
hinge_ofn = 36;
hinge_ifn = 8;

// Zip tie notches
// if nonzero, take a cubical notch this size from the top hinge outside faces
hinge_ztnotch = 0;
```

### hinge_points

List of points to place hinges. Specified as factors applied to
`box_def.x` which define the center point of the hinge assembly.

### hinge_zrat

Defines the point at which the hinge pin should lie, relative to the Z
dimenzion of the box definition (`box_def.z`). This point changes how
the box lid sweeps in over the top as it closes, some combinations of
configurations won't work.

**hinge_zrat** | result (`hinge_standoff` used for illustration)
---------------|-------
`hinge_zrat = 0.1` | 
`hinge_zrat = 0.8`  | 

### hinge_len

Length of a whole hinge, that is the top and bottom taken together.

### hinge_xrat

Ratio by which the hinge is split into the bottom, single part and
thus the top two parts. The bottom part of a hinge is `hinge_len *
hinge_xrat`; the top parts split whatever length remains (less the
value of CLEAR, see elsewhere).



### hinge_basepoint_top
### hinge_basepoint_bottom

Controls the bottom of the hinge leg, for the box top and bottom parts
respectively. May be specified absolute (>1) or relative to the part
height (<1). Default 0; which extends the hinge the full box height.

### hinge_root_d

Diameter of cylinder making up the base of the hinge leg. Defaults to
`hinge_id`; increase to make the hinge root larger and more solid.

### hinge_od

The outer diameter of the hinge body cylinder. This dimension governs
the overall Y protrusion of the hinge from the box body.



### hinge_id

The inner diameter of the hole cut for a hinge pin.

### hinge_midpoint

The point at which the hinge begins to shrink into the box body. Is
another cylinder of `hinge_od` diameter and can overlap the hinge
pin. Specified as a factor which is applied to the Z dimension of the
hinge parts, which will lead to different results with different
combinations of other hinge parameters.

### hinge_ztnotch

If nonzero, dimensions a cube taken from the outer faces of the top
hinge parts. Intended for tucking away ziptie ends. Our 4 inch zipties
have 4mm clip ends and fit well in a 4.4mm notch.

### hinge_ofn, hinge_ifn

The `$fn` for the outer and inner hinge cylinders, respectively. Keep
the outer $fn high to ensure parts can rotate freely when in contact,
or use `hinge_standoff` to provide extra clearance if necessary.

### hinge_standoff

Specifies distance to offset hinge in the Y dimension. Offsets the
portion of the hinge body from the cylinder surrounding the hinge pin
to `hinge_midpoint` away from the box body in the Y dimension.

### hinge_mid_hole

If nonzero, another hole will be cut from the hinge midpoint. This
might be used for retaining a single ziptie hinge pin, for example.

-----------------------------------------------------
## Catch Clasps

Catch clasps provide a positive action snap fit closure. A clasp tab
on the box top, which extends past and overlaps the box bottom when
closed. A matching catch tooth on the box bottom fits into a hole in
the clasp providing the retention. A catch foot protrudes from the
bottom of the clasp to provide grip and leverage for bending the clasp
past the tooth to open the box.

**PRINTING NOTE** The catch clasps rely on tight tolerance and sharp
  corners on one side and a smoothly rounded shape on the
  other. Depending on your equipment and materials you may be able to
  print them without supports, we've had success doing so. Larger
  openings and longer bridged areas will benefit from supports but may
  be delicate and hard to trim afterwards.

=======================
```
// where to put catch clasps
catch_points = [];

// width of catch clasp (<1 * box_def.x, >1 actual units)
catch_wide = 0.40;

// width of catch clasp bottom (<1 * catch_wide, >1 actual units)
catch_wide_bottom = 0.8;

// width of tooth /  cutout in catch (* catch_wide_bottom)
catch_tooth_xrat = 0.7;

// where on the bottom height the tooth rides
catch_tooth_zrat = 0.3;

// thickness of thicker catch bars; and tooth
catch_thick = false; //wall_thick * 2;

// thickness of catch inner fill
catch_inner_thick = false; //wall_thick;

// $fn for catch corner sphere shapes
catch_fn = 32;

// extra height to take from cutout
catch_hole_xtra = false; //CLEAR;

// space between tooth and catch when closed
catch_offset = false; //CLEAR/2;

// thickness of catch foot piece
catch_foot_thick = false;//catch_thick *2;

// width of foot bar grip piece (* catch_wide_bottom)
catch_foot_xrat = 1.0;
```

**NOTE** Variables defined `false` in this documentation and in the
top of `hingebox_code.scad` are calculated at runtime, if not
overridden by the user. Otherwise they might not be calculated from
the correct values, due to the way variable scoping works. Example
values are shown in comments. You **can** override these values, your
definitions will be used.

### catch_points

Points to place catch clasps, specified as factors applied to
`box_def.x`. Points are the centerline of the clasp, as with hinges.

### catch_wide

How wide the top of the clasp should be, Values less than 1 are
applied as a factor to `box_def.x`, values greater than 1 are used
unmodified.



### catch_wide_bottom

How wide the bottom of the clasp should be. Values less than 1 are
factored against `catch_wide`, values greater than 1 are used
unmodified.

### catch_tooth_xrat

Factor of `catch_wide_bottom` defining the width of the catch tooth,
and the cutout in the catch body into which the tooth fits. Too wide
will leave the catch parts too delicate to use.

### catch_tooth_zrat

Factor defining the height at which the catch tooth sits. 0 is the
bottom of the box, 1 is the bottom of the lip (if `lip_rat` is
nonzero), experimentation may be required to tune this parameter
properly for any particular use case. 

### catch_thick

Maximum thickness of the catch clasp body, and the thickness of the
catch tooth. Defaults to `wall_thick *2` but that will only be
satisfactory for thin walled boxes. Our experiments suggest values
between 1.4 and 3.0 as a good window, much thinner is delicate and
much thicker is hard to operate as it doesn't flex enough. You will
have to be guided by your own results with your equipment.



### catch_inner_thick

Thickness of the inner filling of the catch clasp body. Can be 0 to
remove the reinforcing web entirely, which produced counter-intuitive
results in our testing.

### catch_fn

`$fn` parameter of the hulled hemispheres which make up the catch
body, and the catch tooth. 

### catch_hole_xtra

Extra allowance to remove from the hole around the catch
tooth. defaults to `CLEAR`.

### catch_offset

Goal space between the catch tooth and the catch clasp when the box is
assembled and closed. defaults to `CLEAR/2`.

### catch_foot_thick

Thickness of the catch foot peice, defaults to `catch_thick*2`. Can be
0 to disable the catch foot.

### catch_foot_xrat

Factor of `catch_wide_bottom`, width of the catch foot peice.

### catch_tooth_shape()
```
module catch_tooth_shape( cd, ch, cfn ) { capsule_qtr( cd, ch, cfn ); }
```

Define your own catch tooth shape here if you'd like.

-----------------------------------------------------
## Magwarts

Magwarts are a small rounded protrusion attached to both the box top
and bottom. These are hollowed out to contain magnets, which meet when
the assembled box is closed and provide retention through magnetic
attraction (assuming we've lined the magnets up properly).



We've used 6mm x 2mm rare earth magnets with great success. The usual
cautions about these magnets should be observed; glue them firmly into
your final assembly and handle them with care to ensure children and
other small animals do not inadvertenly consume them.

=======================
```
magwart_points = [];

// as with hinge_zrat; the point at which the magwarts meet in the assembled box
magwart_zrat = 0.5;

// rotation angle for magnet slot. 0 = straight "down", -45 to +45 are likely useful angles.
magwart_slotra = 0;

// how far apart the magnets ride when closed. can be <0 to have the magnets peek out the flats
magwart_offset=false; // 0-CLEAR;

// diameter and height of magnet void (should be 0.3 to 0.6 or so larger than your magnets)
magnet_d =6.3; magnet_h =2.3;

// width of stress relief slot in magwart, 0 to disable
magnet_slot_d = 0.5;

// calculated later, default 
// [round( (magnet_d*1.0)+(wall_thick*2) ), 
//   round( (magnet_d*1.0)+(wall_thick*2) ), 
//   round( magnet_h+(wall_thick*2))]
magwart_box = false;
```

### magwart_points

Points to place magwarts. As with hinges and catch claps, these
specify the centerline of the part, as a factor applied to
`box_def.x`.

### magwart_zrat

Factor applied to `box_def.z`determining height at whigh the magwart
surfaces meet in the assembled, closed box. Like `hinge_zrat`. Should
probably be close to the top/bottom midpoint, or you'll have to
stretch the shape to fit.



### magwart_box

[X,Y,Z] dimensions of the magwart. By default this is calculated from
supplied `magnet_d` and `magnet_h` as shown, by adding `wall_thick *
2` to the magnet size, and rounding that off. The 1.0 values in the
formula above provide an easy place to scale the X or Y and squash the
magwarts into different shapes should you wish.

On boxes with shorter tops, you may need to stretch your magwarts so
they reach. The default formula for calculating the size of the
magwart containing box is essentially "as small as possible" which is
rarely what's needed.

This box has `lip_rat = 0; top_rat = 0.1;`, and `magwart_zrat = 0.8;`.



By distoring the box containing the magwart we extend it far enough to
attach to the box lid even though the magnets' meeting point is
further down the box bottom.

```
magwart_box= [
    round( (magnet_d*2.0)+(wall_thick*2) ), 
    round( (magnet_d*1.5)+(wall_thick*2) ), 
    round( magnet_h+(wall_thick*2))];
```



### magnet_d, magnet_h

The diameter and height, respectively, of the void and channel cut for
magnets. No clearance is added to this number in the code, make your
own allowance for your own parts. We're using 6mm x 2mm magnets and
the default values of 6.3mm x 2.3mm allow them to fit snugly without
quite being impossible to insert.



### magwart_offset

Factor added between the meeting point of the top and bottom magwarts,
when the box is assembled and closed. The default vaule of `0 - CLEAR`
leaves the tips of our 6mm magnets peeking through the surface of the
magwarts and makes for a good solid contact when the boxes close. 

### magnet_slot_d

If nonzero, specifies the width of a channel to cut through the center
of the magwart to the depth of the magnet. This can allow for stress
relief and easier magnet insertion, and may aid retrieval of magnets
if made larger. Other uses may be possible.

### magwart_slotra

Rotation angle of the slot in the magwart. the default 0 is straight
up/down (depending on if it's the top or bottom of the box); values of
-45 to +45 may be useful if there's need to insert magnets from a
different direction.

### magwart_shape()
```
module magwart_shape(d) { qwart(d); }
```

The default shape of the magwarts can be overridden by defining your own
`magwart_shape` module. For example, `module magwart_shape(d) {
cube(d); }` produces cubical magnet pockets:



The parameter `d` in this case will be the same `magwart_box` you've
defined. See the documentation for [Callbacks](#callbacks) for more
discussion about overriding modules.

-----------------------------------------------------
## Screw Towers



Screw towers are a reinforced cylindrical shape inside the box, meant
to hold a screw or ziptie for more permanent or secure closure. 

=======================
```
// points to place screw towers
screw_points = [];

// boolean, do screwtower in the top or bottom half of the box
screwtower_top = true;
screwtower_bottom = true;

// diameters of screw tower
screw_od = 8; screw_id = 3.3;

// factor to multiply screw_od by to brace to wall.
screw_bspread = 1.3;

// how deep the screw hole is (0 for none)
screw_deep = 16;

// $fn for screw tower outside and inside
screw_ofn = 16; screw_ifn = 8;

// reduce the size of the bottom of the screw hole a bit
screw_id_bottom = false; //(screw_id*0.80);

// (bool) have the screw hole go completely through the tower and bottom surface
screw_punchbottom = false;

// height of slot in screw tower (0 to disable feature)
screw_slot_h = 0;

// diameter of slot in screw tower
screw_slot_d = 0;

// extra factor to add to separate slots further or make them closer
// (positive values drive the slots further from each other,
// negative values bring them closer together
screw_slot_xdepth = 0;//(0-CLEAR);
```

### screw_points

Points at which to place screw towers. List of factors applied to
`box_def.x`

### screw_od

The diameter of the outer body of the screwtower.



### screw_bspread

Factor applied to `screw_od`, size of wall brace portion of
screwtower. set near 0 for a more cylindrical tower.

### screw_id

Diameter of the inner hole of screwtowers.

### screw_deep, screw_id_bottom

Depth of screw hole in bottom screwtower, if `screw_punchbottom` is
false. A taper can be applied to the hole with `screw_id_bottom` which
defaults to `screw_id * 0.8`.

### screw_punchbottom

Boolean, if true the bottom screwtower's inner hole will be extended
through the bottom of the box, as the top hole is; and the `hnut_t`
cutout removed from the bottom surface as specified. Also, if true, no
taper will be taken, as the hole is re-reamed.

### screw_ofn, screw_ifn

`$fn` of the outer and inner cylinder shapes comprising the screwtower.

### screwtower_top, screwtower_bottom

Boolean, default true. Set to false to remove the top or bottom
portion of the screwtowers should you wish to do that.

### screw_slot_h, screw_slot_d, screw_slot_xdepth

failed try at magnetic closure, left incase they turn out useful
somewhere. Could be used to hold nuts for internal hardware.

-----------------------------------------------------
## Callbacks
=======================

A "callback" is a do-nothing module, which provides a place for you to
define your own module that does *something* instead. We've defined
the following callback modules:

```
module insert_top( d ) {}
module insert_bottom( d) {}

module decorate_top( d ) {}
module decorate_bottom( d ) {}

module decorate_left( d ) {}
module decorate_right( d ) {}
module decorate_front( d ) {}
module decorate_back( d ) {}

module decorate_top_left( d ) {}
module decorate_top_right( d ) {}
module decorate_top_front( d ) {}
module decorate_top_back( d ) {}

module cutout_top( d ) {}
module cutout_bottom( d ) {}

module cutout_left( d ) {}
module cutout_right( d ) {}
module cutout_front( d ) {}
module cutout_back( d ) {}

module cutout_top_left( d ) {}
module cutout_top_right( d ) {}
module cutout_top_front( d ) {}
module cutout_top_back( d ) {}
```
=======================

These modules are invoked with the appropriate rotations and
translations applied for the face they apply to; and given as a
parameter a box definition `d` defining that face and wall
thickness.




Any OpenSCAD code can be applied to any face easily. To make use of
this feature in your script, define a module named `decorate_top` (or
whichever name you need, read on) which accepts a parameter `d`, as
shown above. This module will then be called by the box script and
included at the right time.

For example, placing a text label on the inside top of the box:
```
module decorate_top( d ) { #linear_extrude() { text("Snafu" ); } }
```


Utility functions are provided for performing several of the things we
wanted done. The code above puts that text at the corner of the face,
and probably isn't the desired size. We have provided a [utility function](#utilities)
to [scale and center](#center_scale) objects:

```
module decorate_top( d ) { center_scale( d, 0.42 ) { linear_extrude() { text("Snafu" ); } } }
```


`insert_bottom` and `insert_top` are hooks to place structure inside
the top and bottom of the box. The provided [`diecut()`](#diecut) and
[`dividers()`](#dividers) utility modules allow for quick creation of
internal dividers. Our example boxes may include more complicated, custom
inserts.

`insert_` modules are given a definition that includes the full volume
of their box half. If you need to have structure projecting past the
division point of the box top and bottom, using the provided `d.z`
won't be sufficient.




The bottom faces of the box are named `front`, `back`, `right` and
`left`; where the hinges are on the back of the box, and the clasps on
the front. The top faces are named `top_front`, `top_back`,
`top_right` and `top_left`. As the box is laid out in preview these
faces are rotated, but on assembly everything lines up correctly.

There are also callbacks for `top` and `bottom` which apply to the
**inside** faces of the whole inside area of the box top and
bottom. Placing protruding decorations under the 0 Z level can
certainly work but is likely to require more detailed effort and slicer
support than we wish to detail here. Cutouts on those faces backed by
walls for strength can give good results without requiring extra
effort.

`cutout_` modules are translated to *inside* the wall, `decorate_*`
modules are translated to just outside (or above) their wall. Both are
given a definition of X and Y of the sides of the face, and Z of
`wall_thick`. The area possibly lost as a result of `corner_radius` is
not accounted for in the code.





No provision is made to keep decorations and cutouts and
inserts from colliding or interfering with each other.

-----------------------------------------------------
## Parts

These are shapes to attach to boxes.

### Dovetails

We've provided a pair of interlocking dovetail shapes for making
groups of boxes that join together, or whatever other use such might
be put to. The dovetail rail part slides into the block, and depending
on the tolerances and clearances provided the resultant joint can be
tight enough to require significant force to open or can be simple
to slide apart.



The specification of the dovetail shape applies only to that shape,
these variables do not affect the other box features, but the
same definition should be shared between the block and rail calls.

### dtspec

Vector of 5 numbers, which describe the dovetail shape.
```
dtspec = [height, top_wide, bottom_wide, taper=0, breakpt=0]
```

Where `height` is the heigth of the dovetail shape, `top_wide` is the
widest width, `bottom_wide` is the shorter width, at the bottom.
taper (if nonzero) is subtracted from the `top_width` of one end of
the dovetail tounge or positive shape, smoothly over the entire peice,
or if breakpt is nonzero, from breakpt to the end.



### dovetail_rail()
=======================
```
module dovetail_rail( tlen, dtspec )

    tlen - block length
    dtspec = [height, top_wide, bottom_wide, taper=0, breakpt=0]
              dovetail profile
    tpr - (=0) taper subtracted from one end. make negative to reverse
    tbk - (=0) point along length to begin tapering off
```


Dovetail rail of `dtspec` profile and `tlen` length.

### dovetail_block()
=======================
```
module dovetail_block( d, dtspec, clr=CLEAR )

    d - block desc (outside of notch)
    dtspec - dovetail profile, see dovetail_rail()

    note: no taper is taken from the notch shape
```


Block of dimensions specified by [X,Y,Z] vector `d`, with a dovetail
void removed from the center. `clr` is added to the dimensions of the
void, that is, removed from the block... Increase the value of `clr`
to make the final joint more loose, decrease `clr` to make the joint
tighter.

Our default `CLEAR` of 0.6mm results in dovetail joints that
are some effort to join and take apart, but survive repeated cycles of
assembly and disassembly well. Your circumstances may require
adjusting this factor.

### wartclip()
=======================
```
module wartclip( bd, thick, ra=0 ) {

    bd - bounding box
    thick - how thick the clip part is (at the top of the bounding box)
    ra - rotation angle to apply to clip body. 0 is parallel, ~ 10 will have the tip touching base level

```

Based on the same distorted quarter shphere as the magwarts, this
shape can be used as a belt clip, or loop. `thick` controls the top
leg that connects to the box, as well as the thickness of the clip
body. We've found 5mm strong enough to use and not too thick.

the rotation angle `ra` can be used to turn the tip of the clip
inwards towards the box body; perhaps providing a titghter grip on the
belt. It might be harder to print depending on your slicer.

To make a belt loop with this, place two, one rotated 180 degress from
the other.

-----------------------------------------------------
## Utilities

We've provided some utility modules to make it easier to do the things
we needed done and things we imagined others might need.

Several of these routines share the paramaters `d` to define the box; and
`scl` as a scaling factor. The scaling factor is applied to the X and
Y dimensions of the box `d` leaving Z alone.

### diecut()
=======================
```
module diecut(d) {}

- trims child objects to the base_box shape described by <d>

    d - [x,y,z] box definition
```

This provides for neatly cutting internal inserts so they don't poke
out of corners when using a larger `corner_radius` Could also be used
for rounding corners for decorative surfaces. Uses existing
`corner_radius` etc.

If this routine is cutting your objects too short, adjust `d.z`

Without `diecut()` | With `diecut()`
------------------|------------
 | 

### center_scale()
=======================
```
module center_scale( d, scl ) {}

- X/Y centers and scales children in box <d>. NOTE uses resize() so may be slow.

    d - [x,y,z] box definition
    scl - factor by which to multiply d for scaling.
```

Too handy not to have. resizes and relocates children to fit in `scl`
of box `d`. No worries about what size the clipart you want on the box
top is; but probably lots of effort to get it to scale without
distortion. If that's your need look at the **auto** flag on the
OpenSCAD [`resize` function](https://en.wikibooks.org/wiki/OpenSCAD_User_Manual/Transformations#resize).

Without `center_scale()` | With `center_scale()`
------------------|------------
 | 

### slots(), yslots(), and grid()
=======================
```
module slots(d, scl, hsz, t=wall_thick ) 
module yslots(d, scl, hsz, t=wall_thick )
module grid(d, scl, hsz, t=wall_thick )

        d, scl - as above
        hsz - size of hole (gap between walls)
        t - thickness of wall (default wall_thick)
```

Routines to to make grids on 1 or both dimensions, constrained to
center/scaled portion of box <d>. Note that's constrained by uneven
division; not scaling. Asymmetrical results can be expected from
these.

Given: `d = [100,100,10]; scl = 0.75;`

Call |  Results
-------|---------
 `slots(d, scl, 9 );`  | 
 `yslots(d, scl, 9 );`  | 
 `grid(d, scl, 9 );`  | 

### cyl_grid()
=======================
```
module cyl_grid( d, scl, sz, iv, xfn=$fn )

- create a grid of cylinders (holes), center/scaled to box <d>

    d - [x,y,z] box definition
    scl - factor to scale by; how much space in <d> to fill 
    sz - size (diameter) of cylinder
    iv - interval, space between cylinders
    xfn - cylinder $fn
```


This also scales by rough division and will not completely fill the
scaled area where that does not evenly divide by the specified size
`sz` and interval `iv` parameters. The idea is for quick
perforations, thus:

```
module cutout(d) { cyl_grid(d, 0.60, 3, 4.8, 6 ); } 
//  Apply our cutout() module to each face we want perforated
module cutout_top( d ) { cutout(d); }
module cutout_bottom( d ) { cutout(d); }
module cutout_left( d ) { cutout(d); }
module cutout_right( d ) { cutout(d); }
```

This creates a grid of 6 facet cylinders, 3mm diameter, 4.8mm spacing,
over about 60% of the area of box `d`, and incises from the 4 faces of
the box.



### dividers()
=======================
```
module dividers( d, xdiv, ydiv, h, t=wall_thick )

- create divider walls as defined by xdiv and ydiv lists

    d - 3vec [x,y,z] box definition
    xdiv - points along d.x to make dividers <h> high and <t> thick
    ydiv - same for d.y  (either list may be empty.)
    h - height of wall
    t - thickness of wall (defaults to wall_thick)
```

For use with `insert_top` and `insert_bottom` (possiibly useful
elsewhere); creates walls along either X or Y axes at defined
points.

The points specified in `xdiv` and `ydiv` are, if lewss that one (1),
taken as factors to apply to that dimension. Values greater than one
are used as absolute units for positioning.

To create a cross shape that divides a box into 4 sections:

```
module insert_bottom( d ) {
    diecut(d) {
        dividers(d, [0.5], [0.5], d.z);
    }
}
```


If you'd like two dividers along one dimension, instead:

```
module insert_bottom( d ) {
    diecut(d) {
        dividers(d, [0.25, 0.75], [0.5], d.z);
    }
}
```


If you'd like the division in one dimension to be shorter, you could
call the module twice:

```
module insert_bottom( d ) {
    diecut(d) {
        dividers(d, [], [0.5], d.z / 2 );
        dividers(d, [0.25, 0.75], [], d.z);
    }
}
```

### cylinder_half(), capsule(), capsule_qtr()
=======================
```
module cylinder_half( cd, ch, cfn=$fn ) 
module capsule( cd, ch, cfn=$fn ) 
module capsule_qtr( cd, ch, cfn=$fn )

- Sortof cylinderish shapes useful for multiple purposes.

    cd - cylinder diameter
    ch - cylinder height
    cfn=$fn - cylinder $fn

```

`capsule_qtr()` is the default catch clasp tooth; and the other shapes
are documented as they may be handy for other uses too.

Call | Result
------|-------
`cylinder_half( 10, 20 );` | 
`capsule( 10, 20 );` | 
`capsule_qtr( 10, 20 );` | 

-------------------------------
   Copyright (c) 2019 Mark and Marie Lamb. Distributed under GPLv3, see LICENSE file for terms.

We hope you find this code useful, and ask that you **[hit this donate
link](https://www.paypal.com/cgi-bin/webscr?cmd=_s-xclick&hosted_button_id=J3AY8SM43A2DA&source=url)**
please.

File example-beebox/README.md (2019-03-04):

# Mark's Enclosure Helper - Bee Box

We wanted to have an example that showed perforations for the [Let's
Build a Beebox](../LETSBUILD-beebox.md) tutorial; and though we aren't
actually beekepers and it's winter so we haven't tried capturing any
insect in this, we think it's work including.




-------------------------------
   Copyright (c) 2019 Mark and Marie Lamb. Distributed under GPLv3, see LICENSE file for terms.

We hope you find this code useful, and ask that you **[hit this donate
link](https://www.paypal.com/cgi-bin/webscr?cmd=_s-xclick&hosted_button_id=J3AY8SM43A2DA&source=url)**
please.

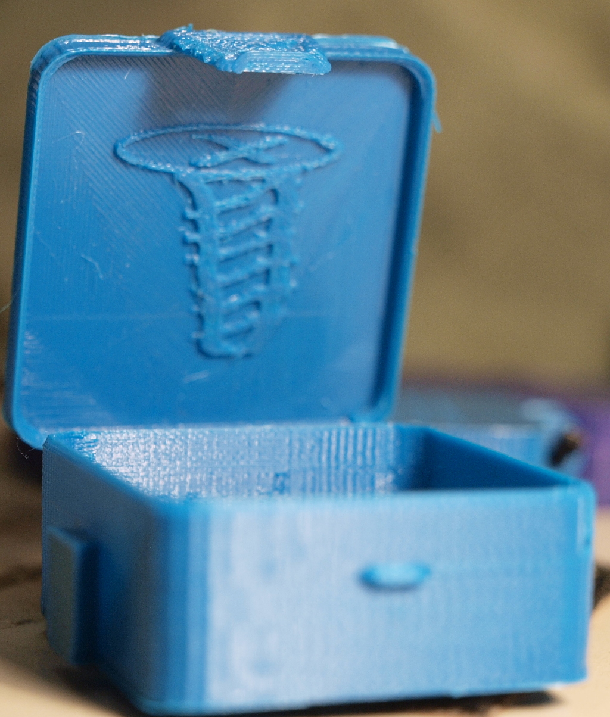
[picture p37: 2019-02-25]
example-partbox/example-partbox-front.jpg

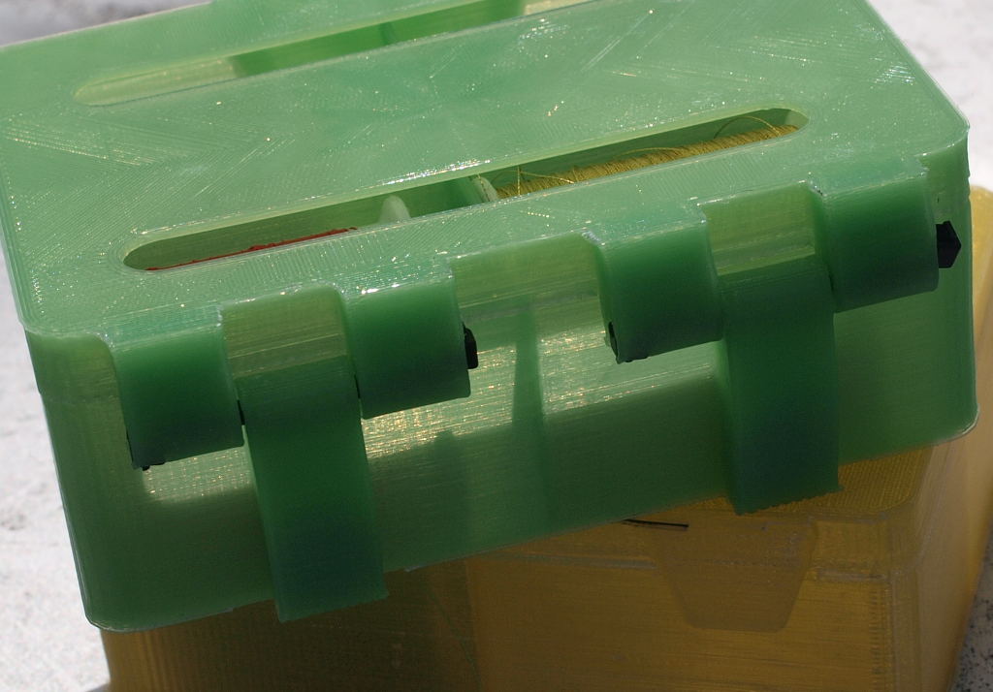
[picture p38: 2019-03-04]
example-threadkeeper/example-threadkeeper-back.jpg

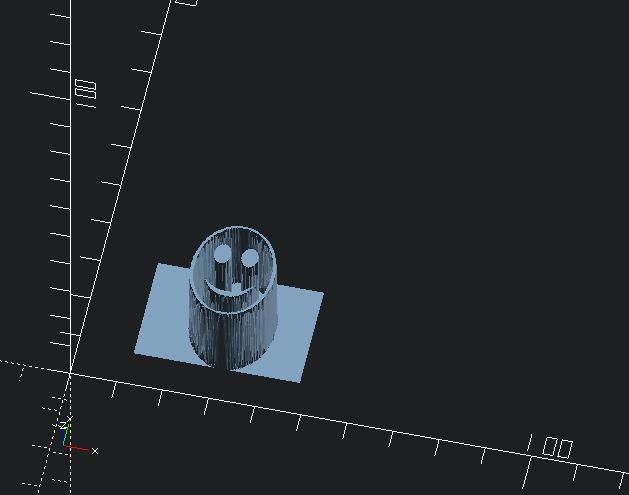
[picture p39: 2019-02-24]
docpix/surface-pvw2.png

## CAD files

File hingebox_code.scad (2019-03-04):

/* ======================================
    Mark's Enclosure Helper
    https://github.com/h2odragon/MarksEnclosureHelper
    
  the values in this file are reasonable defaults, or blank, for a 
  vanilla enclosure experience. include this file in your OpenSCAD
  script and configure your box there. See included examples.

  We hope you find this code useful; and beg you please to 

                   GIVE US SOME MONEY (pretty please)
                   
                   via paypal:
   https://www.paypal.com/cgi-bin/webscr?cmd=_s-xclick&hosted_button_id=J3AY8SM43A2DA&source=url
  
   And we thank you for your support.
   
   Copyright (c) 2019 Mark and Marie Lamb. Distributed under GPLv3, see LICENSE for terms.
   
========================================== */

MEH_VERSION = "20190304";


// ============================== VARIABLES ====================  

// ========== BOX  ========== 

// width (x), depth (y), height (z)
box_def = [60, 30, 30]; 

// wall thickness (all around)
wall_thick = 2;  

// how much height (z) is top (rest is bottom)
top_rat = 0.15;  

// height (z) of lid lip overlap chamfer (0 to disable). 
//  (should be less than top_rat)
lip_rat= 0;  

// box corner radius
corner_radius = 8;  

// box corner $fn
corner_fn = 16;     

//nut inset dia and nut inset thick (depth)  
// used in hinge and screw tower, disable by setting hnut_t = 0
hnut_d = 6; hnut_t = 0; 

// space between hinge parts, top/bottom screw towers
CLEAR=0.6;  

// ========== HINGES ========== 

// height of hinge axis; % of total height (aka dz or box_def[2] )
hinge_zrat = 0.70; 

// points along width (x)  to place hinges, leave empty for none
hinge_points = [ ];  
  
// length of single hinge; splits top/bottom by hinge_xrat
// anything under 10 is probably too delicate to use
hinge_len = 16; 

// how much hinge_len is bottom tower. (>1 taken as a concrete unit)
//   ( the hinge top splits the rest in half, on the outside of the lower hinge)
hinge_xrat = 0.33; 

// if you want to separate the hinge towers from the box body
hinge_standoff = 0; 

// where the hinge leg bends (z), % of hinge height
hinge_midpoint = 0.5; 

// where the hinge leg ends. <1 * lz, >1 taken absolute.
hinge_basepoint_bottom = 0;
hinge_basepoint_top = 0;

// diameter of hinge root cylinder
hinge_root_d = false; // hinge_id;

// the diameter of the outer hinge cylinder
hinge_od = 8; 

// hinge_id of 3.8 to 4.0 works for m3 screw and 4in ziptie
hinge_id = 4.0;  

// size of hole to put through hinge_midpoint; 0 to disble
hinge_mid_hole = 0;


// outer $fn for hinge, and inner $fn for hinge pin hole
// keep outer high; hinges rub the other half of the box without standoff
hinge_ofn = 36;
hinge_ifn = 8;

// Zip tie notches
// if nonzero, take a cubical notch this size from the top hinge outside faces
hinge_ztnotch = 0;

// ========== CATCH CLAPS ========== 

// where to put catch clasps
catch_points = [];

// width of catch clasp (<1 * box_def.x, >1 actual units)
catch_wide = 0.40;

// width of catch clasp bottom (<1 * catch_wide, >1 actual units)
catch_wide_bottom = 0.8;

// width of tooth /  cutout in catch (* catch_wide_bottom)
catch_tooth_xrat = 0.7;

// where on the bottom height the tooth rides
catch_tooth_zrat = 0.9;

// thickness of thicker catch bars; and tooth
catch_thick = false; //wall_thick * 2;

// thickness of catch inner fill
catch_inner_thick = false; //wall_thick;

// $fn for catch corner sphere shapes
catch_fn = 32;

// extra height to take from cutout
catch_hole_xtra = false; //CLEAR;

// space between tooth and catch when closed
catch_offset = false; //CLEAR/2;

// thickness of catch foot piece
catch_foot_thick = false;//catch_thick *2;

// width of foot bar grip piece (* catch_wide_bottom)
catch_foot_xrat = 1.0;

// ========== MAGWARTS ========== 

magwart_points = [];

// as with hinge_zrat; the point at which the magwarts meet in the assembled box
magwart_zrat = 0.5;

// rotation angle for magnet slot. 0 = straight "down", -45 to +45 are likely useful angles.
magwart_slotra = 0;

// how far apart the magnets ride when closed. can be <0 to have the magnets peek out the flats
magwart_offset=false; // 0-CLEAR;

// diameter and height of magnet void (should be 0.3 to 0.6 or so larger than your magnets)
magnet_d =6.3; magnet_h =2.3;

// width of stress relief slot in magwart, 0 to disable
magnet_slot_d = 0.5;

// calculated later, default 
// [round( (magnet_d*1.0)+(wall_thick*2) ), 
//   round( (magnet_d*1.0)+(wall_thick*2) ), 
//   round( magnet_h+(wall_thick*2))]
magwart_box = false;


// ========== SCREW TOWERS ========== 

// points to place screw towers
screw_points = [];

// boolean, do screwtower in the top or bottom half of the box
screwtower_top = true;
screwtower_bottom = true;

// diameters of screw tower
screw_od = 8; screw_id = 3.3;

// factor to multiply screw_od by to brace to wall.
screw_bspread = 1.3;

// how deep the screw hole is (0 for none)
screw_deep = 16;

// $fn for screw tower outside and inside
screw_ofn = 16; screw_ifn = 8;

// reduce the size of the bottom of the screw hole a bit
screw_id_bottom = false; //(screw_id*0.80);

// (bool) have the screw hole go completely through the tower and bottom surface
screw_punchbottom = false;

// height of slot in screw tower (0 to disable feature)
screw_slot_h = 0;

// diameter of slot in screw tower
screw_slot_d = 0;

// extra factor to add to separate slots further or make them closer
// (positive values drive the slots further from each other,
// negative values bring them closer together
screw_slot_xdepth = 0;//(0-CLEAR);

// ========== LAYOUT ========== 

// show ghosts, top/bottom and magnets
VIS=true;  

// extra space between top and bottom for printing
PART_SPACE= 4; 

// ======================================= USER REDEFINES 

// decorate functions are translated and rotated to the appropriate face, and given a 3vec definition of the face's size with a Z of wall_thick. see examples for ways to make use of this.
// inside
module decorate_top( d ) {}
module decorate_bottom( d ) {}

// bottom
module decorate_left( d ) {}
module decorate_right( d ) {}
module decorate_front( d ) {}
module decorate_back( d ) {}

module decorate_top_left( d ) {}
module decorate_top_right( d ) {}
module decorate_top_front( d ) {}
module decorate_top_back( d ) {}

module cutout_top( d ) {}
module cutout_bottom( d ) {}

module cutout_left( d ) {}
module cutout_right( d ) {}
module cutout_front( d ) {}
module cutout_back( d ) {}

module cutout_top_left( d ) {}
module cutout_top_right( d ) {}
module cutout_top_front( d ) {}
module cutout_top_back( d ) {}

module insert_top( d ) {}
module insert_bottom( d) {}

module magwart_shape(d) { qwart(d); }
module catch_tooth_shape( cd, ch, cfn ) { capsule_qtr( cd, ch, cfn ); }


// ======================================== CODE  
// ========================= utilities 

/* =========================
    cyl_grid( d, scl, sz, iv, xfn ) - create a grid of holes, center/scaled to box <d>

    d - [x,y,z] box definition
    scl - factor to scale by; how much space in <d> to fill 
    sz - size (diameter) of cylinder
    iv - space between cylinders
    xfn - cylinder $fn
   ========================= */
module cyl_grid( d, scl, sz, iv, xfn=$fn ) {
    // grid of regular cylinders constrained within scaled space
    sd=d*scl; 
    xdivs=sd.x/(iv);
    ydivs=sd.y/(iv);
    xrt = (d.x*(1.0-scl)/2);
    yrt = (d.y*(1.0-scl)/2);
    for (ix=[0:xdivs]) {
        xpt = ix * iv;
        for (iy=[0:ydivs]) {
            ypt = iy * iv;
            translate( [xrt+xpt,yrt+ypt,0-CS] ) cylinder( d=sz, h=d.z+CS2, $fn=xfn);
        }
    }
}

/* =========================
    routines to to make grids on 1 or both dimensions, 
      constrained to center/scaled portion of box <d>

    slots(d, scl, hsz, t ) 
    yslots(d, scl, hsz, t )
    grid(d, scl, hsz, t )

        d, scl - as above
        hsz - size of hole (gap between walls)
        t - thickness of wall (default wall_thick)
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

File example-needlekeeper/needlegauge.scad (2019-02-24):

// copyright (c) 2019 Marie Lamb. Licensed GPLv3 as part of Mark's Enclosure Helper project.
module NeedleGauge() {
$fn=25;
rdxp=-75;
rdn=5;
divisions = [  // y place, label
        [0,  "0 "],
        [8,  "  1  "],
        [16, "     2"],
        [24, "        3"],
        [30, "            4"],
        [36, "                6"],
        [42, "                      8"]
    
    ];
    mirror([1,0,0])
    scale([.5,.5,.5])
    for (rddef=divisions) {
         translate([rdxp+rddef[0],5,1.9]) 
  rotate([180,0,0])
                linear_extrude(height=1){ text( rddef[1] );  }
            }
            
difference() {

scale([1,.25,.015])
    translate([0,-20,0])
cube(80,true);

//size 0 - 2 mm
    translate([35,-10,0])
rotate([0,0,90])
cylinder(10,1,1,true);

//size 1 - 2.25 mm
    
 translate([28,-10,0])
rotate([0,0,90])
cylinder(10,1.125,1.125,true);

//size 2 - 2.75 mm

 translate([19,-10,0])
rotate([0,0,90])
cylinder(10,1.375,1.375,true);

//size 3 - 3.25 mm

 translate([9,-10,0])
rotate([0,0,90])
cylinder(10,1.625,1.625,true);

//size 4 - 3.5 mm

 translate([-2,-10,0])
rotate([0,0,90])
cylinder(10,1.75,1.75,true);

//size 6 - 4.0 mm

 translate([-14,-10,0])
rotate([0,0,90])
cylinder(10,2,2,true);

//size 8 - 5mm
 translate([-28,-10,0])
rotate([0,0,90])
cylinder(10,2.5,2.5,true);


}

}

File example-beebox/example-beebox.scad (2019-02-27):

include <../hingebox_code.scad> // uses github.com/h2odragon/MarksEnclosureHelper

hingedbox( box_def );
//myperf( box_def );

box_def = [60, 40, 20]; 
wall_thick = 1.2;  

top_rat = 0.20;  
lip_rat= 0.10;  

hinge_points = [0.5];
hinge_len = 24; 

catch_points=[0.5];

screw_points = [0.4, 0.6];
screw_punchbottom = true;

module myperf(d) {
    cyl_grid(d, 0.60, 3, 4.8, 6 );
} 

module cutout_top( d ) { myperf(d); }
module cutout_bottom( d ) { myperf(d); }
module cutout_left( d ) { myperf(d); }
module cutout_right( d ) { myperf(d); }

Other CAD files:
example-cardcase/example-cardcase.scad
example-eyeglass-beltcase/glasses-case.scad
example-minitin/example-minitin.scad
example-needlekeeper/example-needlekeeper.scad
example-partbox/example-partbox.scad
example-threadkeeper/example-threadkeeper.scad

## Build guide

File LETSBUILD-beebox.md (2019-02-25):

# Mark's Enclosure Helper
## Let's Build a Bee Box

  https://github.com/h2odragon/MarksEnclosureHelper

Copyright (c) 2019 Mark and Marie Lamb. Distributed under GPLv3, see LICENSE for terms.

 - [Basic Box](#basic-box)
 - [Hinges](#hinges)
 - [Catch Clasps](#catch-clasps)
 - [Screw Towers](#screw-towers)
 - [Cutouts](#cutouts)

If you've never used OpenSCAD before, we suggest you spend some time
reading the [official
documentation](http://www.openscad.org/documentation.html) and
tutorials available at the OpenSCAD web site and eslewhere. This
tutorial is aimed to help you create a box without any OpenSCAD
experience, but we encourage learning how to use this truly excellent
tool.

You should have downloaded and installed OpenSCAD already. (We're using
version **2015.03**, the current release as of this writing.) When was
say "create your own SCAD file"; this file can be located wherever
you like. For now is probably best located in the same directory
you've unpacked the Mark's Enclosure Helper package into; the
`hingebox_code.scad` file will need to be in the same directory as
your code.

Following along with this tutorial creates your own version of the
`example-beebox.scad` file. You might name it `my-beebox.scad` if you
like. Either place it in the same directory as the
`hingebox_code.scad` file, or copy that file to your working directory
(preferable for more complicated projects, later).

--------
## Basic Box

Begin your box by creating a new OpenSCAD file. Put these two lines
near the top:
```
include <hingebox_code.scad>
hingedbox( box_def );
```
This includes all of the `hingebox_code.scad` file into yours, and
invokes the `hingedbox` module in it to create the box.

>_(Because the `hingebox_code.scad` file is several hundred lines, the
>console window on your OpenSCAD will report line numbers in error
>messages that don't match those in your editor window.)_

When you preview this, you should see the generic default box.

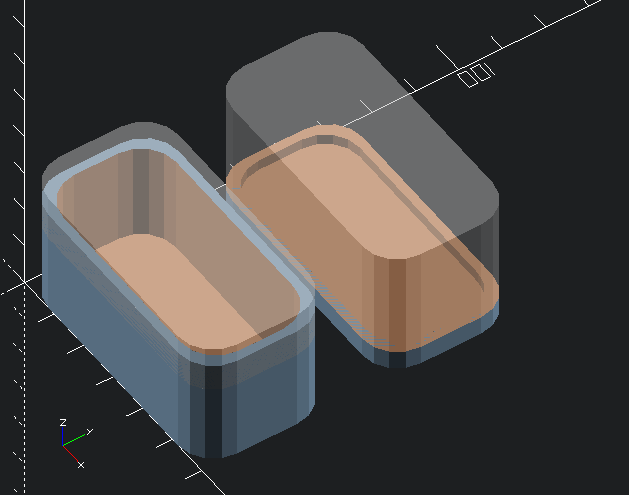
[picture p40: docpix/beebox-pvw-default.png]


>_"What's the grey stuff?" That's the other half of the box, visualized
>in its eventual place, as a ghost image. If you dont want this it can
>be turned off at any time by putting `VIS=false;` in
>your script._

>Under the OpenSCAD Design menu, we suggest the "Automatic Reload and
>Preview" option be **on**. This updates the view of the object every
>time you save (which can be done with CTRL-S). We suggest you do this
>very, very often. Train your fingers to use
>CTRL-S to update the preview instead of F4 or F5; and you may be glad
>of it later. 

After the line, `hingedbox( box_def );`, start adding definitions to
make this box fit your purpose. These go after the `include` line, to
ensure they are the last definitions of these values. OpenSCAD only
listens to the last thing it heard.

The first thing to set will be the size:
```
include <hingebox_code.scad>
hingedbox( box_def );

box_def = [60,40,20];
```

This defines our completed, closed box dimensions as 60mm wide (X
dimension), 40mm deep (Y dimension), and 20mm tall. The are the
**OUTSIDE** dimensions, the inside will be this minus two walls.

Now we set some of the other variables:
```
include <hingebox_code.scad>
hingedbox( box_def );

box_def = [60,40,20];
wall_thick = 1.2;

top_rat = 0.20;
lip_rat = 0.10;
```

`wall_thick` is the thickness of the walls, which includes outside
walls of the box and is used for other structures as may be needed.

`top_rat` and `lip_rat` define the height (Z) of the top/bottom split,
and the height of the overlapping lip. These numbers are multipliers
applied to `box_def.z`, so in our example will result in a box top
of `box_def.z` * `0.2` = 4mm and therefore a bottom of 16mm. The 2mm
of lip will appear on both halves of the box, it overlaps when the box
is closed.

Your preview window should now look similar to this:

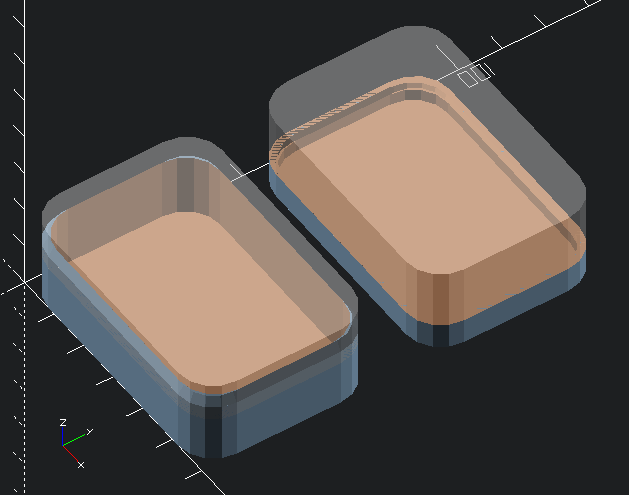
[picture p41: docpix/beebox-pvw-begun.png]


-----------
## Hinges

Next let's put a hinge on it. This is a small box and a single hinge
should be fine. We specify its size and placement:
```
hinge_points = [0.5];
hinge_len = 24;
```

`hinge_points` is a list of points to place hinges. In this case
there's just one item. Each point in that list is a multiplier applied
to `box_def.x`; this example results in one hinge at the middle of the
back of the box. Two hinges at 25% and 75% of the box width could be
specified as: `hinge_points = [0.25, 0.75];`.

`hinge_len` specifies that the hinge, overall, should be 24mm
wide. The ratio of the top and bottom portions of the hinge and other
features can also be varied, see the reference for
[`hinge_xrat`](REFERENCE.md#hinge_xrat) when you wish to do that.

----------
## Catch Clasps

To keep the box closed when we want it closed, let's put a catch clasp
on, by adding:
```
catch_points = [0.5];
```
to our file. The catch clasp is a tab on the front of the box top that
slides over and catches a tooth on the box bottom. Specifying `0.5`
means we want a single clasp, centered at half of the box width
(`box_def.x`).

You can modify the placement, thickness, and proportions of the clasps
in several ways, see the [catch clasps](REFERENCE.md#catch-clasps)
reference for details. For now, we'll stick with the defaults.

Your file should look like this:
``` 
include <hingebox_code.scad> 
 
hingedbox( box_def ); 

box_def = [60, 40, 20]; 
wall_thick = 1.2;  

top_rat = 0.20;  
lip_rat= 0.10;  

hinge_points = [0.5];
hinge_len = 24; 

catch_points=[0.5];
```
And your preview window like this:

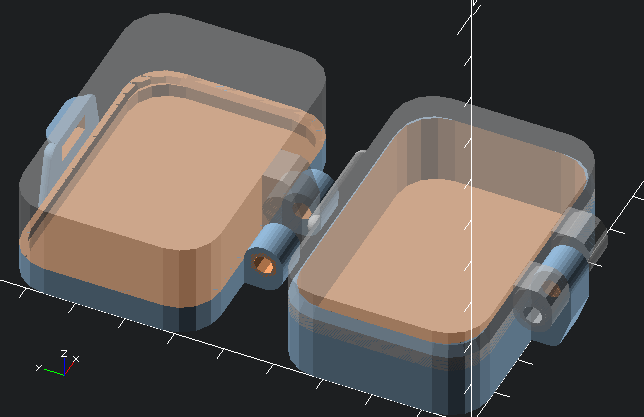
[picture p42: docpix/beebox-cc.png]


This is a complete and functional box as is, but for this example we
have a few more things to do. This catch clasp is a reasonable closure
but we may want a more secure box, if we're say mailing insects
around.

--------------
## Screw Towers

A screw tower is a reinforced column in the top and bottom inside of
the box, with a hole through it for a screw. Specify a pair thus:
```
screw_points = [0.4, 0.6];
```

In this case we want the bottom of the box to be punctured, and the
hole to go all the way through, so we could use a ziptie to secure the
box closed. So we'll add:

```
screw_punchbottom = true;
```

Resulting in a box that looks like:

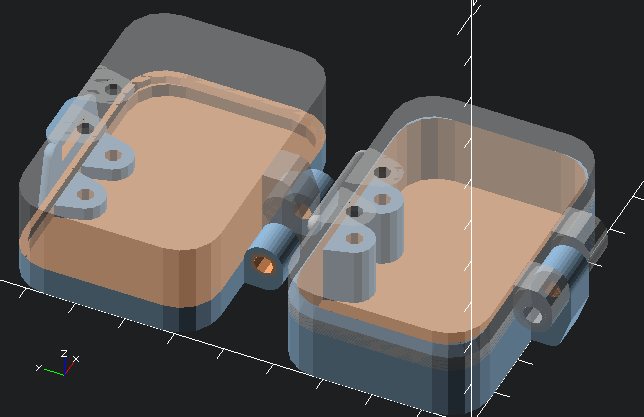
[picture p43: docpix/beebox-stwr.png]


See the [screwtower reference](REFERENCE.md#screw-towers) for all the
options available to change the shape and behavoir of this part. For
the moment the most important variables to you are probably [`screw_od`](REFERENCE.md#screw_od)
and [`screw_bspread`](REFERENCE.md#screw_bspread) which control the
diameter and wall brace size of the screw tower. We'll stick with the
defaults for now.

-------------
### Cutouts

Our box is a complete thing now; but lacks an essential detail. To be a
fit temporary home for living things, it will need ventilation. We've
provided some utilities that make that easy.

We'll use the [`cyl_grid()`](REFERENCE.md#cyl_grid) module to generate
a pattern of cylinders, which we will then remove from the wall of our
box. Define a module thus:
```
module myperf(d) {
    cyl_grid(d, 0.60, 3, 4.8, 6 );
} 
```

`d` will be provided when the module is called, as a `[x,y,z]` box
definition. We can use our `box_def` for testing.

This creates a grid of cylinders of 3mm diameter, with 4.8mm spacing,
with 6 facets on the cylinders. The grid is sized and centered in 60%
of the box defined by `d`. Where that division comes out uneven it
will produce a short grid, which is acceptable for our purpose here.

At top of your script, comment out the `hingebox` invocation, and add
a call to your module to test it.

> _"Comment out" in this case means add two slashes to the beginning of
> the line, in case that term is unfamiliar._

Your script should look like this:
```
include <hingebox_code.scad> 
 
//hingedbox( box_def );   //  <-- NOTE COMMENTED
myperf( box_def);

box_def = [60, 40, 20]; 
wall_thick = 1.2;  

top_rat = 0.20;  
lip_rat= 0.10;  

hinge_points = [0.5];
hinge_len = 24; 

catch_points=[0.5];

screw_points = [0.4, 0.6];
screw_punchbottom = true;

module myperf(d) {
    cyl_grid(d, 0.60, 3, 4.8, 6 );
} 
```
and should produce a preview like this:

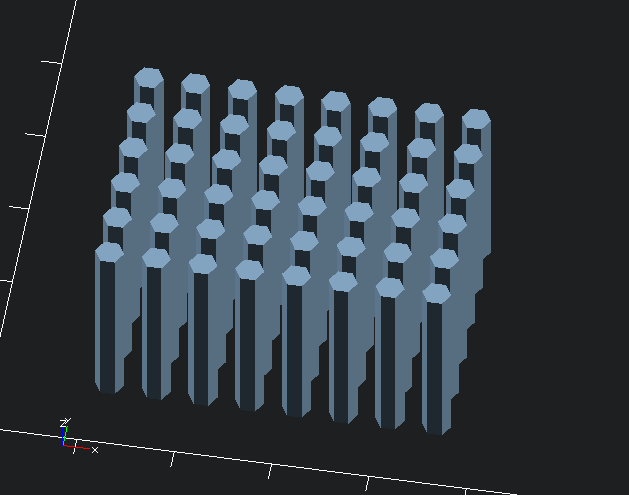
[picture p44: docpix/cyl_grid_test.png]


>Commenting out the `hingedbox` line leaves our `myperf` module the
>only thing being created and shown, which makes things much easier
>when debugging a creation. The actual location of those lines ins't
>terribly important, they can be at the end of the file or even
>somewhere in the middle if you like; but we find it more clear to do
>things this way. The first thing you see when you look at the script
>is what it's doing.

Now we apply our pattern to the faces we want to perforate by adding
the following lines to our script (at the bottom, after the closing
brace of the `myperf` definition):

```
module cutout_top( d ) { myperf(d); }
module cutout_bottom( d ) { myperf(d); }
module cutout_left( d ) { myperf(d); }
module cutout_right( d ) { myperf(d); }
```

Un-comment `hingebox` invocation (and comment out your `myperf`
invocation). As the box is built the `cutout_top`, bottom, left
and right modules get called with `d` defined for each face, which
results in our cylinder pattern being created for each face's size,
then subtracted from that face. See the reference for
[callbacks](REFERENCE.md#callbacks) for everything you can do here.

The whole script should look similar to this:
```
include <hingebox_code.scad>

hingedbox( box_def );
//myperf( box_def );      // <--NOTE

box_def = [60, 40, 20]; 
wall_thick = 1.2;  

top_rat = 0.20;  
lip_rat= 0.10;  

hinge_points = [0.5];
hinge_len = 24; 

catch_points=[0.5];

screw_points = [0.4, 0.6];
screw_punchbottom = true;

module myperf(d) {
    cyl_grid(d, 0.60, 3, 4.8, 6 );
} 

module cutout_top( d ) { myperf(d); }
module cutout_bottom( d ) { myperf(d); }
module cutout_left( d ) { myperf(d); }
module cutout_right( d ) { myperf(d); }

```

Producing an object like:

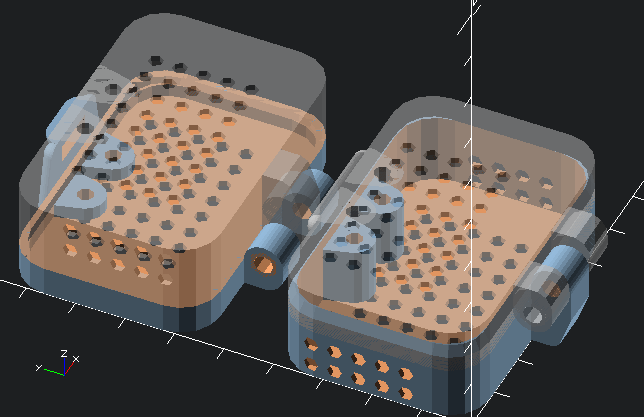
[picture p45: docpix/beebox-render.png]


Congratulations! You can now render your box (using **F6**), export it
as an STL file, take that into your slicer and print away.

These should be very easy to print, we've had success with and without
supports, with and without a print cooling fan, and with several
nozzle sizes. We've even had succesful boxes that functioned despite
layer shifts and other common printing errors.

Assembling the box is pretty straightforward; we have illustrated a
technique for installing [ziptie hinge
pins](REFERENCE.md#box-assembly) or you should be able to use an M3
screw and nut as a hinge pin. Other options are limited only by the
imagination. :)

When finished, this box looks like this:


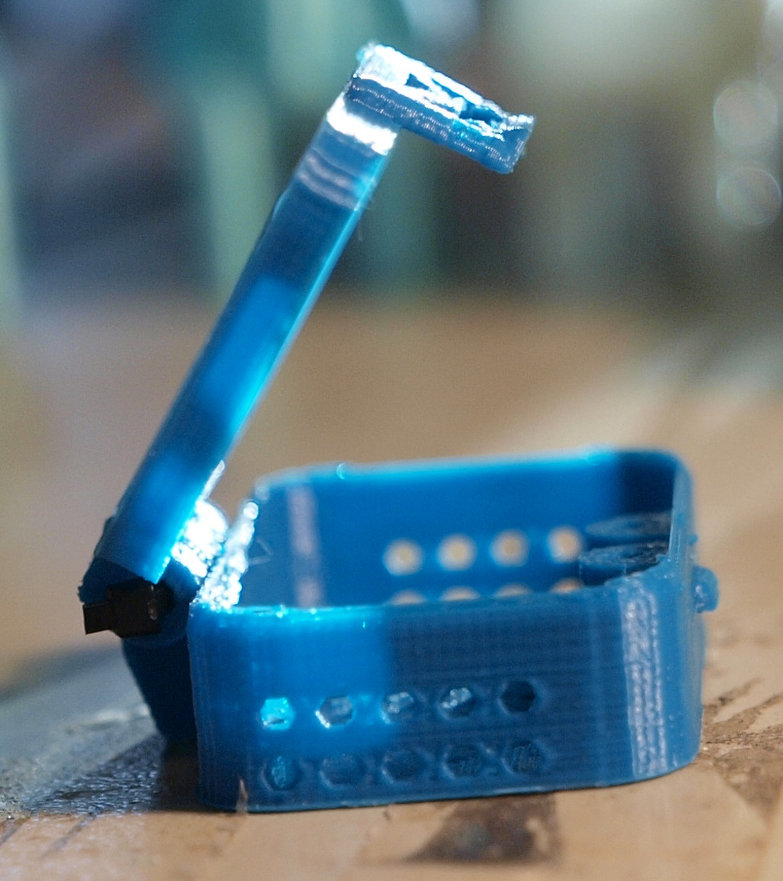
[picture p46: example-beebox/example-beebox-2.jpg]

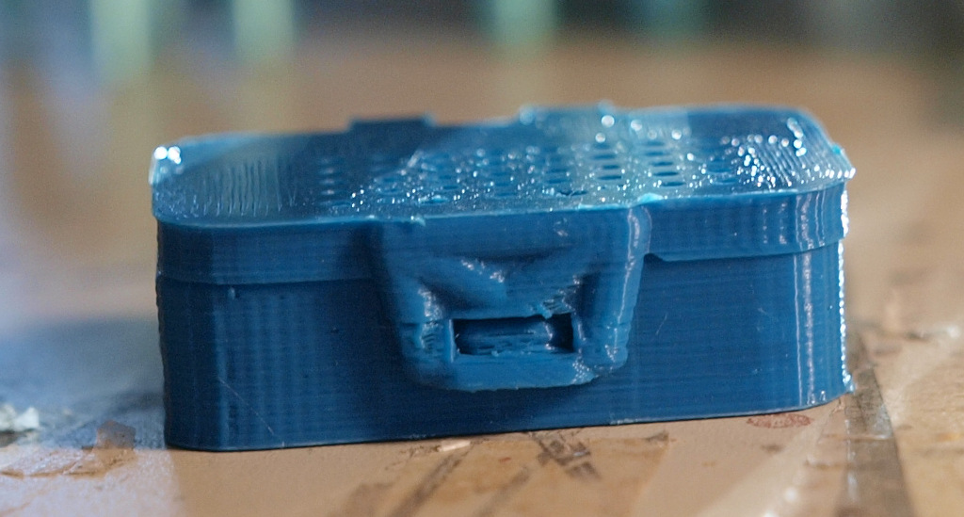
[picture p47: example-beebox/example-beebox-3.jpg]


This is not all Mark's Enclosure Helper can do; see the other examples
for more possibilities.

If you find this project useful, **[PLEASE DONATE](https://www.paypal.com/cgi-bin/webscr?cmd=_s-xclick&hosted_button_id=J3AY8SM43A2DA&source=url)**, thanks!

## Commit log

2019-02-24 pics of prototypes
2019-02-25 update buttons
    [hingebox_code.scad]
2019-02-25 more printed pix
    [example-threadkeeper.scad]
2019-02-25 add url
    [hingebox_code.scad]
2019-02-25 remove buttons
2019-02-25 more pix of printed
2019-02-27 hingework
    add hinge_basepoint_*, hinge_root_d,
    [hingebox_code.scad]
2019-02-27 attrib update
    [example-beebox.scad, example-cardcase.scad, example-minitin.scad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]
2019-03-01 qwart finds more uses
    [hingebox_code.scad]
2019-03-02 Create glasses-case.scad
    Eyeglass case to clip to a belt, with embossed name down the front
    [glasses-case.scad]
2019-03-04 pics and docs
    fill in pics and docs
    mve wartclip to main code
    [glasses-case.scad, hingebox_code.scad]
